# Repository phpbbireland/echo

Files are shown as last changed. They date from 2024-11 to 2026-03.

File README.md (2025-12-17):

# echo (Keyboards)
This is the final repository for all prior keyboard development code, and hardware.

Models included are: 
+ Alya: ayla80 (iso/ansi)
+ Cashel: cashel100 (ansi/iso)
+ Mioke: xpad (macro/num pad)
+ Echo: test code for RP2040 ayla80 (iso).
+ EN015_60_AKL (iso)
+ EN014 (iso) June 2025

The current STM32F411 keyboard code works for all versions, however, the RGB is not tested, to put it simply, I don't know how to implement the RGB code as including it resulted in compile errors, best use the RP2040 modulesfor now.  

Moved on to version 2.x of the Keyboard Development Modules (these have a single 34 pin 1.27mm pitch connector), otherwise they are the same...

**Latest Updates**  
I have switched to my RP2040 Development Module as everything works perfectly, no more issues with RGB...  
Going forward, I will use this for all development but may revisit my STM32F411 development board later...

**Important Notes**  
On all my Keyboad PCB's, the 34 pin connetor is mounted on component side (bottom) of PCB.  
On moules with a 34 pin connector, it is mounted on ***bottom*** of PCB, not the component side (top), see image below.  
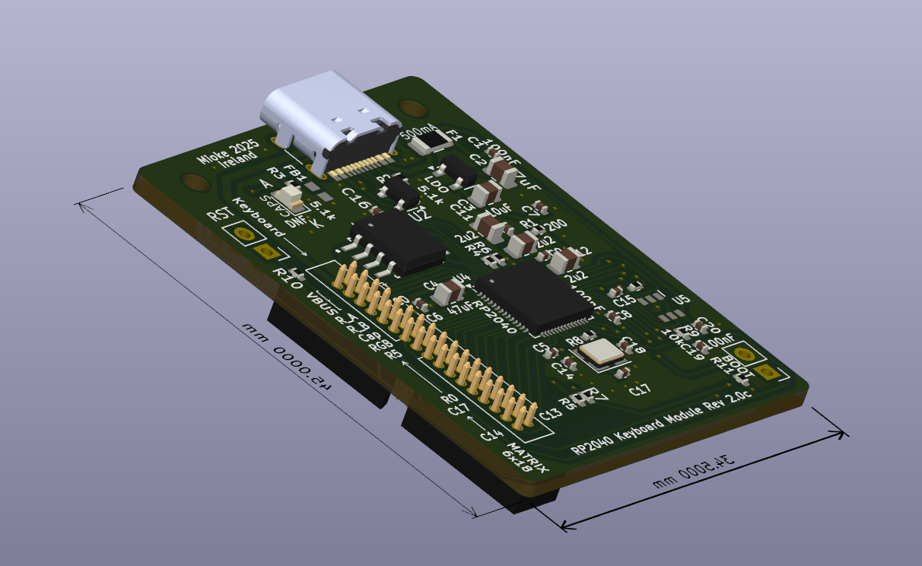
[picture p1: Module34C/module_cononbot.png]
Module


**Revision D**
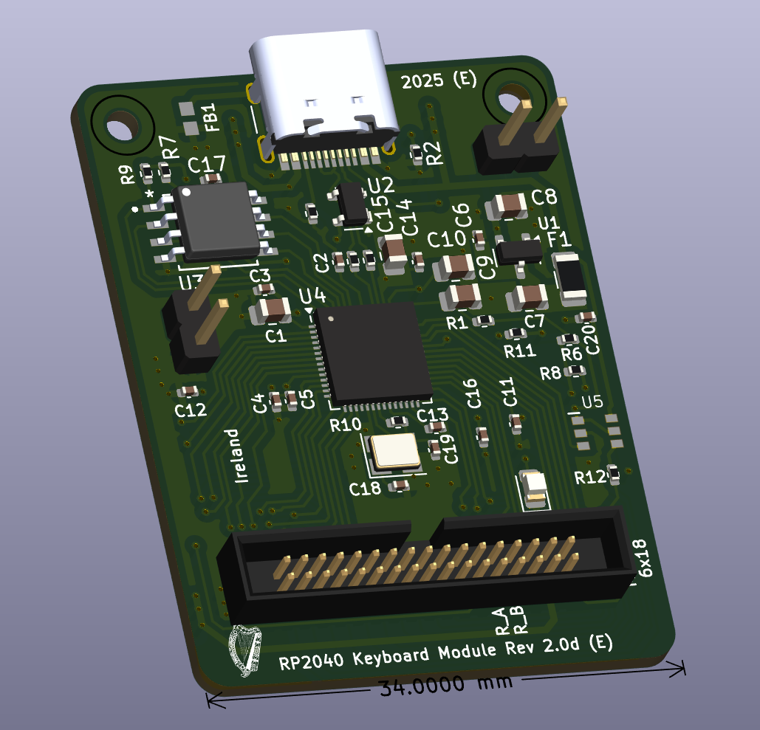
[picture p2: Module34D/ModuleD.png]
Module

*Updates:*  
+ Connector now mounted on component side...  
+ Orinitation change 90°...

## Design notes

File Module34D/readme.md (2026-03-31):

**Version D**

Micros: RP2040  
Module  

Software Supported QMK/VIA: [Link](https://github.com/phpbbireland/echo/tree/main/E014/qmk)  
Switches: MX type hot-swappable  
Keys: Up to 119 Keys (including Macro Keys) + Encoder Switch  
Rotary Encoder: Volume / RGB.  

Tested with [Basic Keyboard](https://github.com/phpbbireland/echo/tree/main/E014)

There are three Keyboard Modules (latest Rev 2D) to give away, thanks to PCBWay, if you are interested in trying out the module, contact me at my [Hackaday Link](https://hackaday.io/project/198392-keyboard-development-module-qmk-via)  

**These files may have updates, please check pin naming and orintation before prooceeding***  
I will update as time allows...

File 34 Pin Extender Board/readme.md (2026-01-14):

# Extender Board  

34 pin 1.27mm connector to 2 x 20 pin 2.54mm header adapter board.  
Kicad files included...
Gerber files update, previous has mirrored silkscreen...

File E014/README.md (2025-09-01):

# echo EN014

**Files for KiCad (ISO)**  
Final Basic Keyboard (EN014) June 18th 2025.  
Includes Plate files...  
Keyboard Layout Editer [Image, col/row numbering](https://github.com/phpbbireland/echo/blob/main/E014/images/kle_en014_keyboard_layout.png)  
Files require addition libraries: marbastlib, ScottoKeebs and library containing SK6812-E, will add soon or you can find these on github...  

**Macro Key:**  
M0 to M9 are Macro Keys, program as required...  

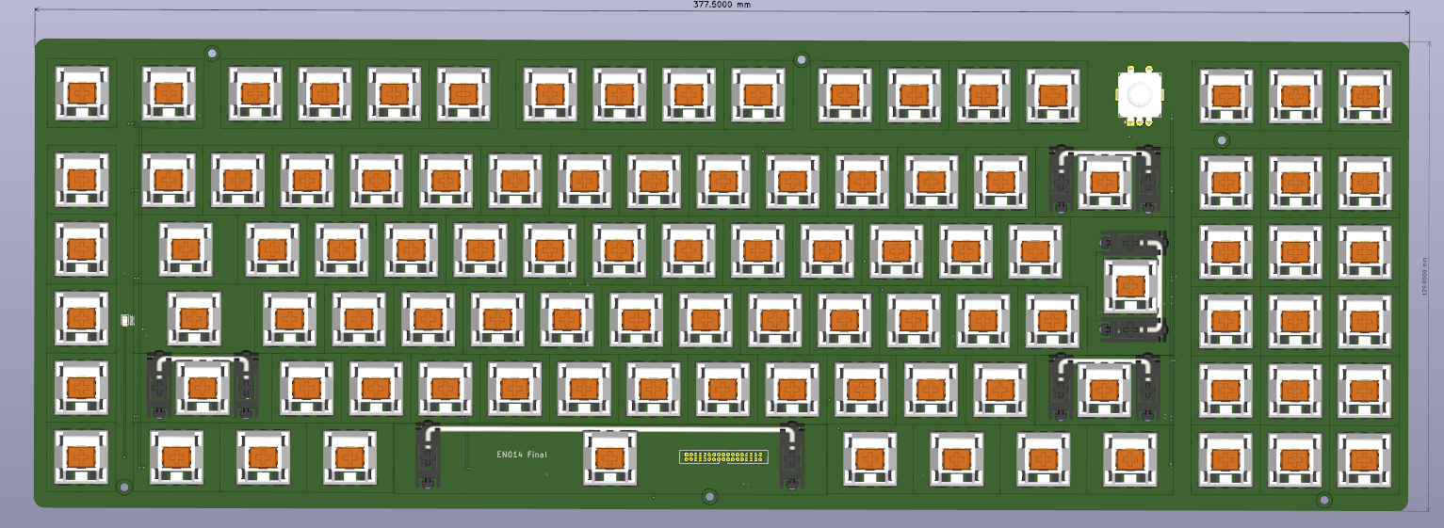
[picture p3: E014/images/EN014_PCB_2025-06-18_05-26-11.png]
PCB
The EN014 Keyboard PCB   
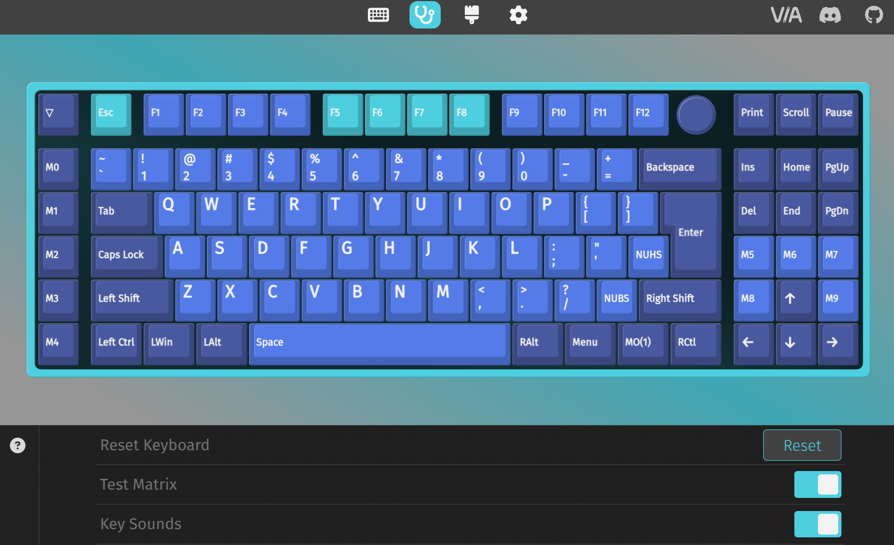
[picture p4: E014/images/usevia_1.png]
usevia
Use Via App window: 
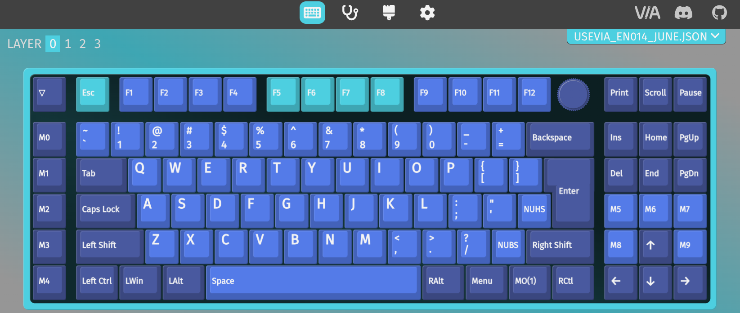
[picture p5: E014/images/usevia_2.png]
usevia

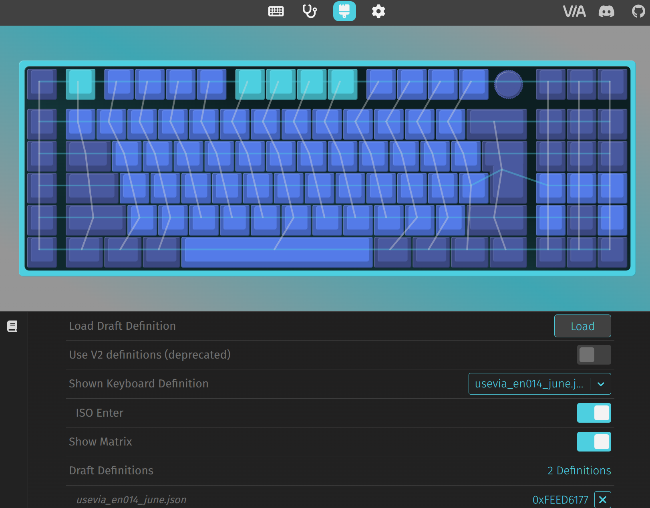
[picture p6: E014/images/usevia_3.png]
usevia
  

**Printed Case & Plate:**  
I have designed a 3D printed enclosure/case for the Keyboard, both printed in two parts with dove tail for best fit/alignment. See echo/EN14/images folder for case.png and case-top.png.
Will also included the keyboard plate print (again in two parts) as it is much cheaper than any other material and has a pleasant sound compared to other materials...

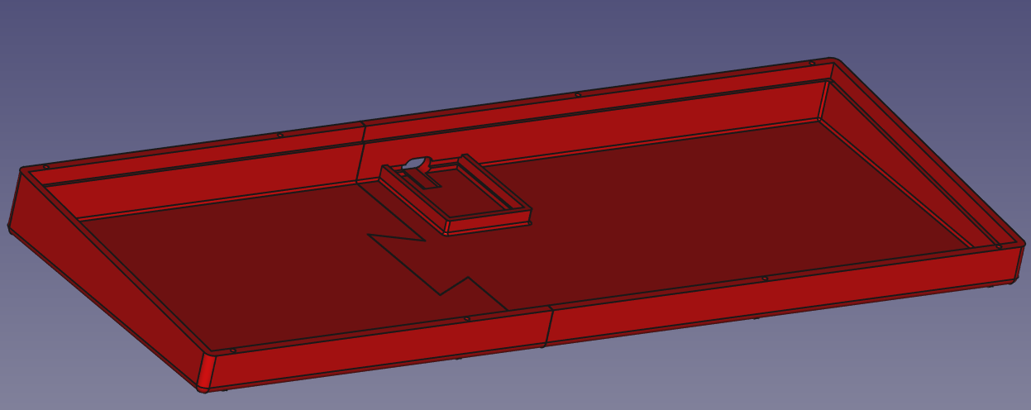
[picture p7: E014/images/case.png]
Case
  
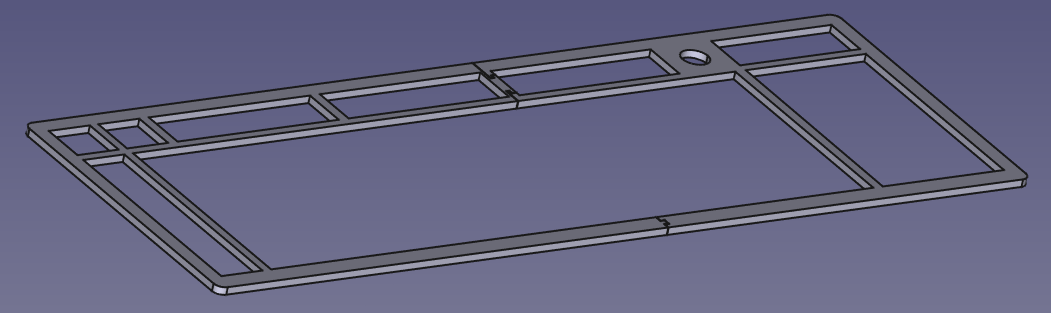
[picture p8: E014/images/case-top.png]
Case Top
  
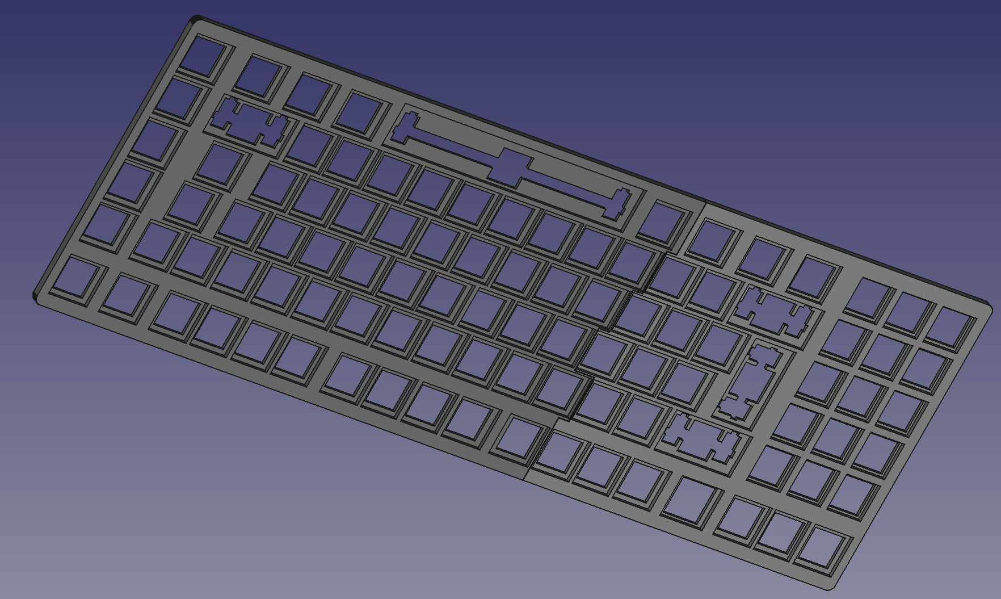
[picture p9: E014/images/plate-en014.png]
Plate
  

**Key Switches:**  
I used Holy Panda Keyboard Switch form Ali, under €20 for 110 switches (they are now my preferred switch on all my keyboards).  
For reference: Holy Panda Tactile Keyboard Switch 3 Pin 55g

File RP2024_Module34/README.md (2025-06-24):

# echo
Files to build the Basic Keyboard and RP2040 Keyboard Development Module

These have been tested with the current code and work flawlessly...
Included: 
+ RP2040_Fullsize_PCBWay_barebones... Basic Keyboard files used in all testing...
+ echo_keyboard_rp2040_module... Slightly smaller module, not produced yet...
+ echo_keyboard_rp2040_module_ori... This is the fully tested module I used in the build. [Image](https://github.com/phpbbireland/echo/blob/main/RP2024_Module34/images/RP2024_Module_Rev0.1.png)
+ iso_encoder_rp2040_en017_brd2...   The QMK and Via code for the project...

A couple of these boards are available (version 1.0, the one with the four RGB leds on it) just contact me...

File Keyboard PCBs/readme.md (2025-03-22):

# Keyboard PCB's
A repository for Keyboard PCB's Kicad Files.

**Basic Keyboard PCB**  
+ Hot-Swappable MX Connectors,
+ Diodes,
+ RBG Leds, 
+ Rotary Encoder
+ A 34 pin 1.27mm connector to connect to a development module (processor) such as my RP2040 Keyboard Development Module.

**Current Boards:**  
+ A 60% keyboard with 6 macro keys (inspired by my AKKO M1)...
+ A 80% keyboard with 12 macro keys...

**Modules:**
+ RP2040 Version 1.x (A 30 pin 1.27mm connector and a 3 pin 2.54mm connector for RGB and Power)...
+ RP2040 Version 2.x (A single 34 pin 1.27mm connector)...
+ STM32F411 Version 1.0 (A single 34 pin 1.27mm connector)...

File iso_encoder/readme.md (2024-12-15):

# echo keyboard ayla STM32F411

*This code is for the new 6x17 matrix with rotary encoder version of the board*

* Keyboard Maintainer: [Michael O'Toole](https://github.com/phpbbireland)
* Hardware Supported: *The PCBs, controllers supported*
* Hardware Availability: *Links to where you can find this hardware*
* Loads in usevia.app...
* iso and ansi...

Kicad Files: Echo_Ayla_Final

Make example for this keyboard (after setting up your build environment):

    make echo/iso_encoder:via 

Flashing example for this keyboard:

    qmk flash echo_iso_encoder_via.bin

See the [build environment setup](https://docs.qmk.fm/#/getting_started_build_tools) and the [make instructions](https://docs.qmk.fm/#/getting_started_make_guide) for more information. Brand new to QMK? Start with our [Complete Newbs Guide](https://docs.qmk.fm/#/newbs).

## Bootloader

Enter the bootloader in 3 ways:

* **Bootmagic reset**: Hold down the key at (0,0) in the matrix (usually the top left key or Escape) and plug in the keyboard
* **Physical reset button**: Briefly press the button on the back of the PCB - some may have pads you must short instead
* **Keycode in layout**: Press the key mapped to `QK_BOOT` if it is available

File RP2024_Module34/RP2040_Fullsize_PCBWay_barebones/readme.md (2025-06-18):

# echo
The kicad file to make the Basic Keyboard PCB...  
Will add kicad libraries etc later or you can find them on github, add as required...

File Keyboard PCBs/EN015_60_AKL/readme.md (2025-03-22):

# EN015_60_AKL
A 60% (89 keys including 6 macro keys) Basic Keyboard.

**Includes:**  
+ Hot-Swappable MX Connectors,
+ Diodes,
+ RBG Leds, 
+ Rotary Encoder
+ A 34 pin 1.27mm connector to connect to a development module (processor) such as my RP2040 Keyboard Development Module.

**Compatible Modules:**
+ RP2040 Version 2.x (A single 34 pin 1.27mm connector)...
+ STM32F411 Version 1.0 (A single 34 pin 1.27mm connector)...

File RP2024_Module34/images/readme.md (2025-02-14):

Connector updated to 34 pin to allow for extra current as single cable is limited to 1 Amp...

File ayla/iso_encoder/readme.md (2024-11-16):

# Echo Keyboards: Ayla (80)

*A short description of the keyboard/project*

* Keyboard Maintainer: [Michael O'Toole](https://github.com/phpbbireland)
* Hardware Supported: *The PCBs, controllers supported*
* Hardware Availability: *Links to where you can find this hardware*

Make example for this keyboard (after setting up your build environment):

    make ayla/iso_encoder:via

Flashing example for this keyboard:

    qmk flash ayla_iso_encoder_via.bin

See the [build environment setup](https://docs.qmk.fm/#/getting_started_build_tools) and the [make instructions](https://docs.qmk.fm/#/getting_started_make_guide) for more information. Brand new to QMK? Start with our [Complete Newbs Guide](https://docs.qmk.fm/#/newbs).

## Bootloader

Current:
* **Blackpill Module** Hold down BOOT button (on Blackpill module),then press and release NRST, release BOOT...

Not implemented yet...

* **Bootmagic reset**: Hold down the key at (0,0) in the matrix (usually the top left key or Escape) and plug in the keyboard
* **Physical reset button**: Briefly press the button on the back of the PCB - some may have pads you must short instead
* **Keycode in layout**: Press the key mapped to `QK_BOOT` if it is available

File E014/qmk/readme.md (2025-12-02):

# Echo EN014 Keyboard Code (June 24th)

+ Create an **echo/en014_june** directory inside: qmk_firmware/keyboards/  
+ Copy all files to qmk_firmware/keyboards/echo/en014_june
+ Change back to the qmk_firmware directory
+ Compile with: make echo/en014_june:via    
+ Copy resulting file (echo_en014_june_via.uf2) to the Module Board (Version 2.x)  

**Note:**
echo.c and echo.h are not required, will remove them (appears to be old method), all RGB matrix data now in keyboard.json.  

**Testing the Module:**  
1 In **Chrome** browser, browse to: https://usevia.app/  
2 Authorize the Keyboard, select: *Michael O'Toole Echo*  
3 Click on the *Design Icon* and browse to the **usevia_en014_june.json** file, select it.  
4 You may need to go back to step 2 and select keyboard again (I do), then test away...  

**More Notes:**  
Tested keyboard operation and RGB, with *Keyboard Development Module* version 2.0, module and code work perfectly.  
EN014 keyboard was designed to work with Module 2.x (the version with the 34 pin connector)...  

Contains electronic files for en014 june 24th

**File to load with usevia.app**  
usevia_en014_june.json

**Compile command for QMK**  
make echo/en014_june:via

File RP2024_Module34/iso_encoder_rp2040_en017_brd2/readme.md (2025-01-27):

# Echo Keyboard with PR2040

Repository for RP2040 keyboard development code, and hardware.  

*Models included are:*
+ Small Development Module/Board for Software Development [link to board](https://hackaday.io/project/198392/log/237192-rp2040-version).
+ Full Keyboard (98 keys/RGB leds, hot-swappable connectors etc.) [link to board](https://hackaday.io/project/202280-basic-hot-swappable-keyboard-with-rgb)
  
Awaiting Development Module (Dec/Jan)...

```
                 ┌─────────┬─────────┬─────────┬─────────┬─────────┬─────────┬─────────┬─────────┬─────────┬─────────┬─────────┬─────────┬─────────┬─────────┬─────────┬─────────┬─────────┬─────────┐
  ┌────────RP2040│  GP0    │   GP1   │   GP2   │   GP3   │   GP4   │   GP5   │   GP6   │   GP7   │   GP8   │   GP9   │  GP10   │  GP11   │  GP12   │   GP13  │  GP14   │  GP16   │  GP17   │  GP18   │
  │              └─────────┴─────────┴─────────┴─────────┴─────────┴─────────┴─────────┴─────────┴─────────┴─────────┴─────────┴─────────┴─────────┴─────────┴─────────┴─────────┴─────────┴─────────┘
  │              ┌─────────┬─────────┬─────────┬─────────┬─────────┬─────────┬─────────┬─────────┬─────────┬─────────┬─────────┬─────────┬─────────┬─────────┬─────────┬─────────┬─────────┬─────────┐
  │     ┌─STMF411│   C13   │   C14   │   C15   │   C0    │   C1    │   C2    │   C3    │   A1    │   A2    │   A4    │   A5    │   A6    │   A7    │   C4    │   C5    │   B0    │   B1    │   B2    │
  │     │        └─────────┴─────────┴─────────┴─────────┴─────────┴─────────┴─────────┴─────────┴─────────┴─────────┴─────────┴─────────┴─────────┴─────────┴─────────┴─────────┴─────────┴─────────┘
  │     │   ┌────┬─────────┬─────────┬─────────┬─────────┬─────────┬─────────┬─────────┬─────────┬─────────┬─────────┬─────────┬─────────┬─────────┬─────────┬─────────┬─────────┬─────────┬─────────┐
  │     │   │    │  COL0   │  COL1   │  COL2   │  COL3   │  COL4   │  COL5   │  COL6   │  COL7   │  COL8   │  COL9   │  COL10  │  COL11  │  COL12  │  COL13  │  COL14  │  COL15  │  COL16  │  COL17  │
┌────┐┌───┐ ├────┼─────────┼─────────┼─────────┼─────────┼─────────┼─────────┼─────────┼─────────┼─────────┼─────────┼─────────┼─────────┼─────────┼─────────┼─────────┼─────────┼─────────┼─────────┤
│GP19││C8 │ │ROW0│ RESET   │ KC_ESC  │ KC_TRNS │ KC_F1   │ KC_F2   │ KC_F3   │ KC_F4   │ KC_F5   │ KC_F6   │ KC_F7   │ KC_F8   │ KC_F9   │ KC_F10  │ KC_F11  │ KC_F12  │ KC_PSCR │ KC_SCRL │ KC_PAUSE│
├────┤├───┤ ├────┼─────────┼─────────┼─────────┼─────────┼─────────┼─────────┼─────────┼─────────┼─────────┼─────────┼─────────┼─────────┼─────────┼─────────┼─────────┼─────────┼─────────┼─────────┤
│GP20││C7 │ │ROW1│ KC_TRNS │ KC_GRV  │ KC_1    │ KC_2    │ KC_3    │ KC_4    │ KC_5    │ KC_6    │ KC_7    │ KC_8    │ KC_9    │ KC_0    │ KC_MINS │ KC_EQL  │ KC_BSPC │ KC_INS  │ KC_HOME │ KC_PGUP │
├────┤├───┤ ├────┼─────────┼─────────┼─────────┼─────────┼─────────┼─────────┼─────────┼─────────┼─────────┼─────────┼─────────┼─────────┼─────────┼─────────┼─────────┼─────────┼─────────┼─────────┤
│GP21││C6 │ │ROW2│ KC_TRNS │ KC_TAB  │ KC_Q    │ KC_W    │ KC_E    │ KC_R    │ KC_T    │ KC_Y    │ KC_U    │ KC_I    │ KC_O    │ KC_P    │ KC_LBRC │ KC_RBRC │         │ KC_DEL  │ KC_END  │ KC_PGDN │
├────┤├───┤ ├────┼─────────┼─────────┼─────────┼─────────┼─────────┼─────────┼─────────┼─────────┼─────────┼─────────┼─────────┼─────────┼─────────┼─────────┼─────────┼─────────┼─────────┼─────────┤
│GP22││B15│ │ROW3│ KC_TRNS │ KC_CAPS │ KC_A    │ KC_S    │ KC_D    │ KC_F    │ KC_G    │ KC_H    │ KC_J    │ KC_K    │ KC_L    │ KC_SCLN │ KC_QUOT │ KC_NUHS │ KC_ENTR │ KC_TRNS │ KC_TRNS │ KC_TRNS │
├────┤├───┤ ├────┼─────────┼─────────┼─────────┼─────────┼─────────┼─────────┼─────────┼─────────┼─────────┼─────────┼─────────┼─────────┼─────────┼─────────┼─────────┼─────────┼─────────┼─────────┤
│GP23││B14│ │ROW4│ KC_TRNS │ KC_LSFT │ KC_Z    │ KC_X    │ KC_C    │ KC_V    │ KC_B    │ KC_N    │ KC_M    │ KC_COMM │ KC_DOT  │ KC_SLSH │ KC_NUBS │ KC_RSFT │         │ KC_TRNS │ KC_UP   │ KC_TRNS │
├────┤├───┤ ├────┼─────────┼─────────┼─────────┼─────────┼─────────┼─────────┼─────────┼─────────┼─────────┼─────────┼─────────┼─────────┼─────────┼─────────┼─────────┼─────────┼─────────┼─────────┤
│GP24││B13│ │ROW5│ KC_TRNS │ KC_LCTL │ KC_LGUI │ KC_LALT │         │         │         │ KC_SPC  │         │         │         │ KC_RALT │ KC_MENU │ M0(FN)  │ KC_RCTL │ KC_LEFT │ KC_DOWN │ KC_RIGHT│
└────┘└───┘ └────┴─────────┴─────────┴─────────┴─────────┴─────────┴─────────┴─────────┴─────────┴─────────┴─────────┴─────────┴─────────┴─────────┴─────────┴─────────┴─────────┴─────────┴─────────┘
```

Matrix Col/Row to GPIO's : RP2040 and STM32F411

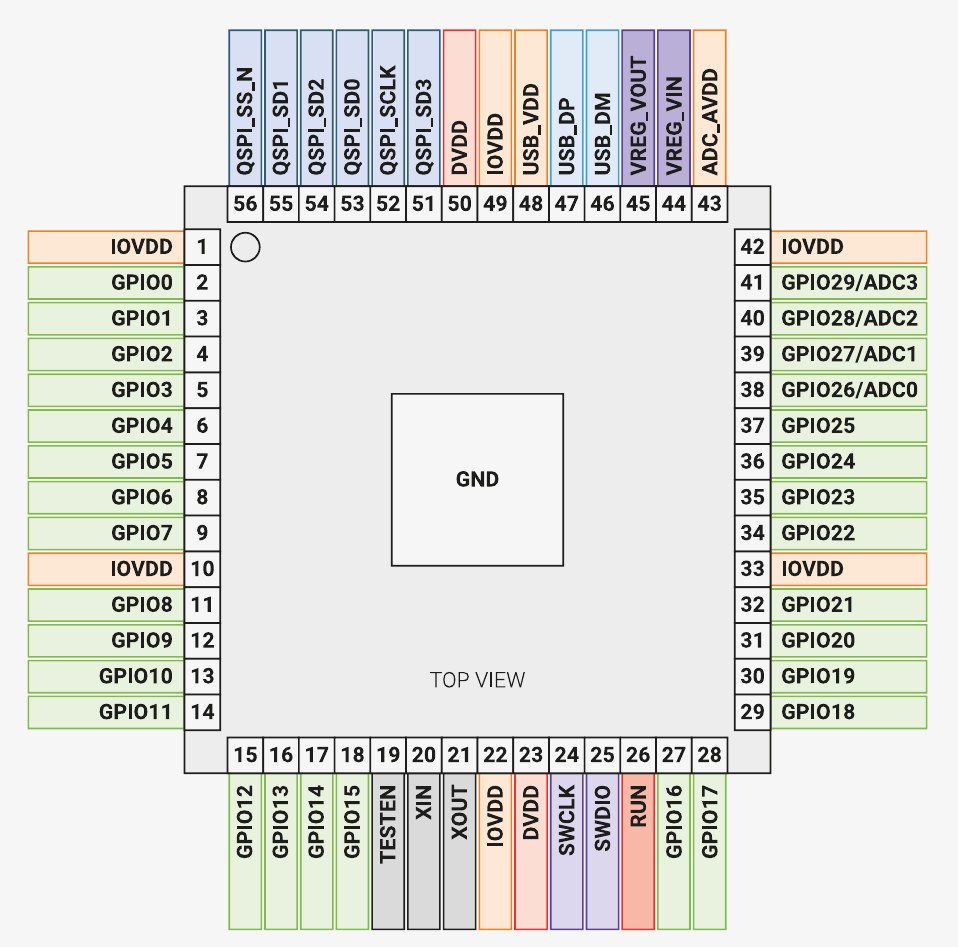
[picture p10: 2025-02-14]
RP2024_Module34/echo_keyboard_rp2040_module_ori/RP2040 Pinout.png

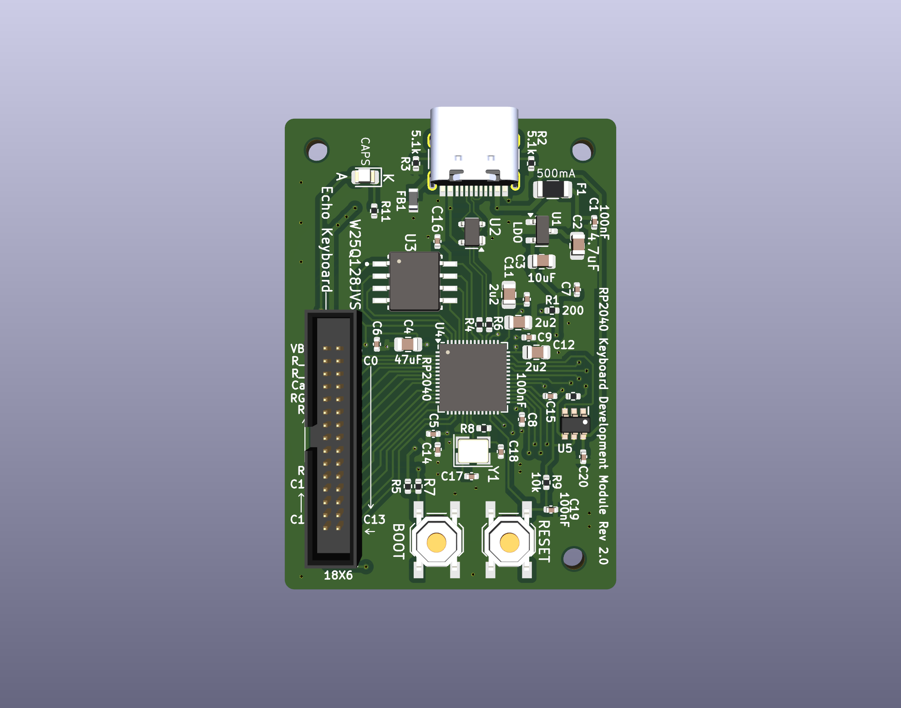
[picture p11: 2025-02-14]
RP2024_Module34/images/RP2024_Module_Rev2.0.png

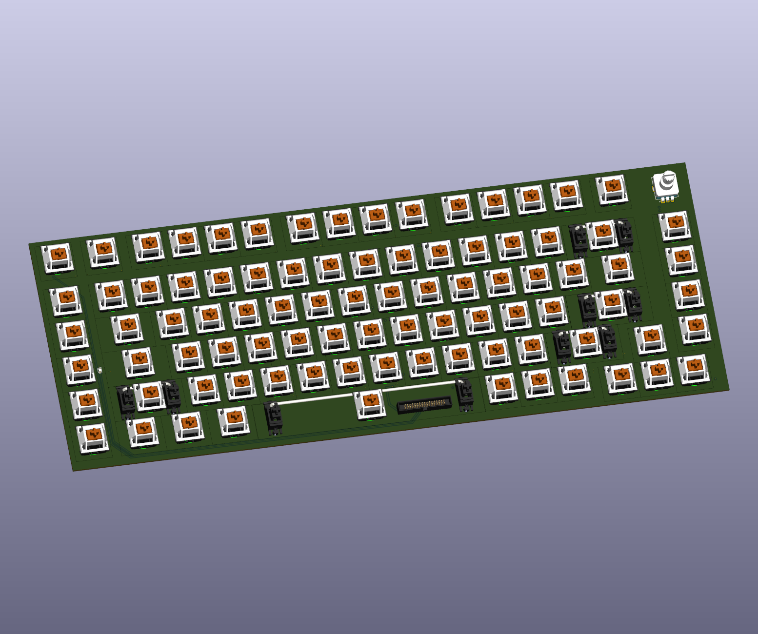
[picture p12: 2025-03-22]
Keyboard PCBs/EN015_60_AKL/images/RP2040_Akko_M1_Like2.png

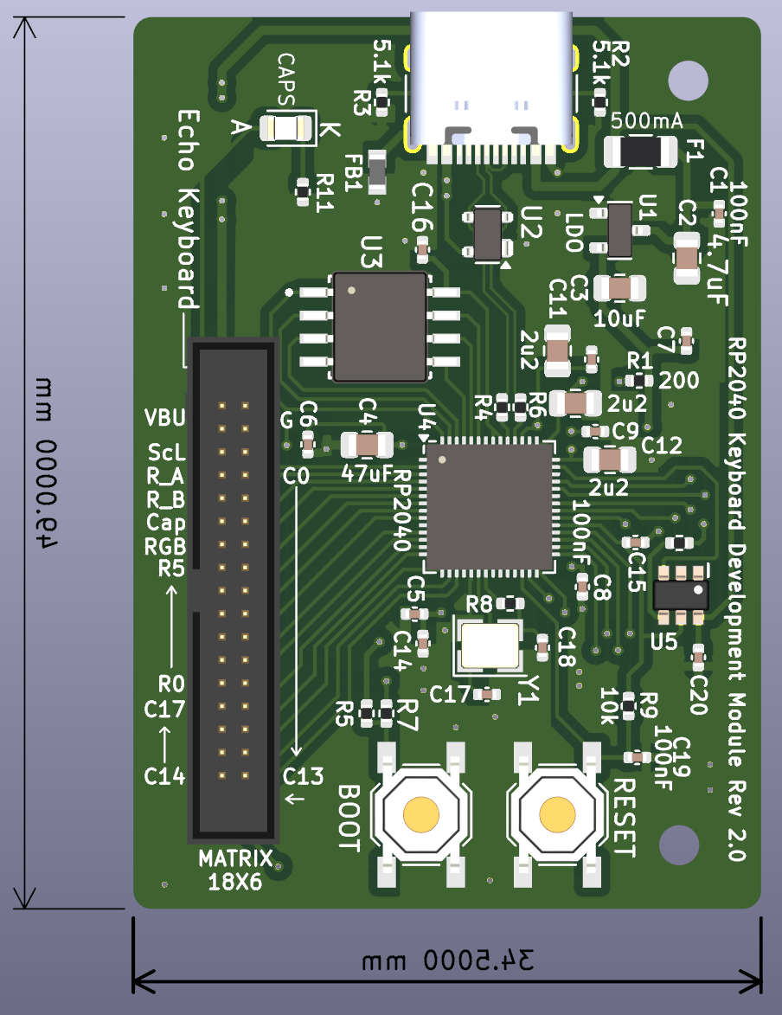
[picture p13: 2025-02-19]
RP2024_Module34/images/RP2024_Module_Rev1.0.png

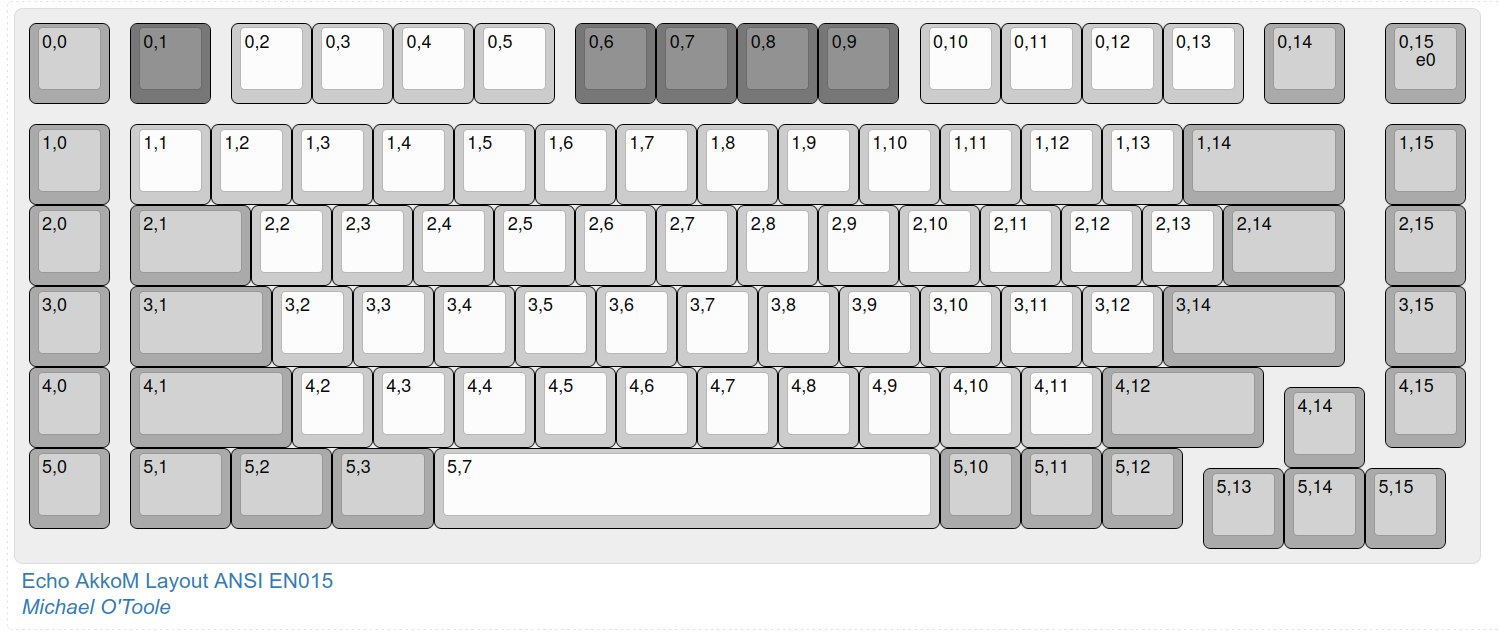
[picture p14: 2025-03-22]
Keyboard PCBs/EN015_60_AKL/images/KLE_Image.png

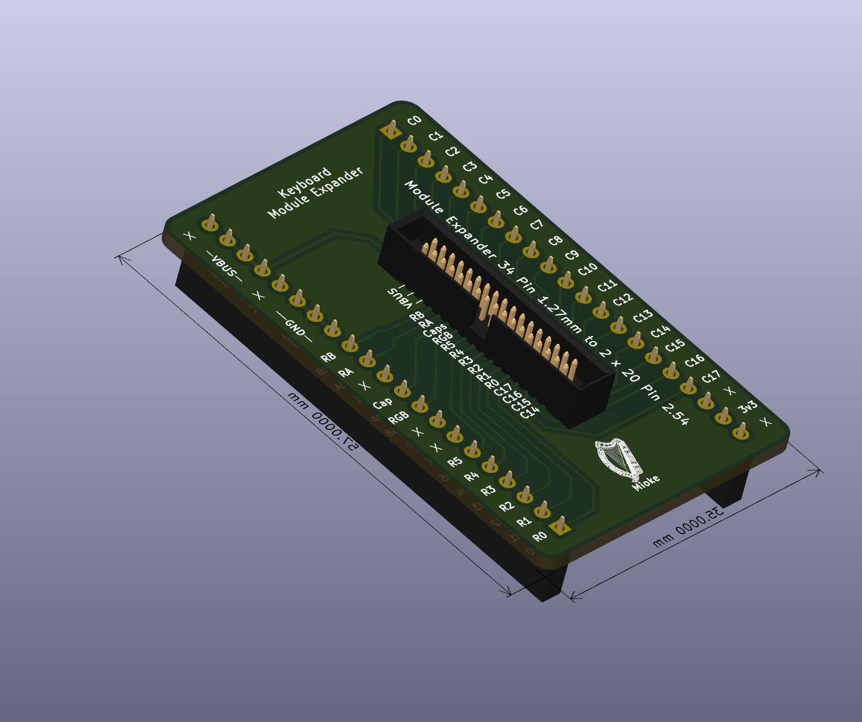
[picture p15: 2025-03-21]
RP2024_Module34/images/adapter34.png

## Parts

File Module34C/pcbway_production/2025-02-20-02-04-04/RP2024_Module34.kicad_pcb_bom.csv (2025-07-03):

Designator | Quantity | Value | Footprint | Package | MPN | DNP | Mount_Type | LCSC | Description | JlcRotOffset | JlcPosOffset | MFP# | MP# | Mfr. Part # | MPN | JLCPCB_CORRECTION
C1, C10, C14, C15, C16, C19, C20, C5, C6, C7, C8, C9 | 12 | 100nF | C_0402_1005Metric | 0402 | CL05B104KB54PNC |  | smt | C307331 | Multilayer Ceramic Capacitors
C11, C12, C13 | 3 | 2u2 | C_0805_2012Metric | 0805 | CL21B225KAFNNNE |  | smt | C19110 | Multilayer Ceramic Capacitors
C17, C18 | 2 | 15p | C_0402_1005Metric | 0402 | CL05C150JB5NNNC |  | smt | C86285 | Multilayer Ceramic Capacitors
C2 | 1 | 4.7uF | C_0805_2012Metric | 0805 | CL21A475KAQNNNE |  | smt | C1779 | Multilayer Ceramic Capacitors
C3 | 1 | 10uF | C_0805_2012Metric | 0805 | CL21A106KOQNNNE |  | smt | C1713 | Multilayer Ceramic Capacitors
C4 | 1 | 47uF | C_0805_2012Metric | 0805 | CL21A476MQYNNNE |  | smt | C16780 | Multilayer Ceramic Capacitors
F1 | 1 | 500mA | Fuse_1206_3216Metric | 1206 | ASMD1206-150 |  | smt | C135341 | Multilayer Ceramic Capacitors
FB1 | 1 | 600R | BEADC1608X95N | 0603 | BLM18AG601SN1D |  | smt | C19330 | Ferrite bead, small symbol
J1 | 1 | USB_C_Receptacle_USB2.0 | USB_C_31-M-12 | SMD | TYPE-C-31-M-12A |  | smt | C5337088 | USB 2.0-only 16P Type-C Receptacle connector | 180 | 0,1.5 | TYPE-C-31-M-12A
J3 | 1 | Conn_02x17_Odd_Even | IDC_2X17_1.27MM | IDC Connectors | X1270WV-2x17B-6TV01 |  | tht | C5147222 | Generic connector, double row, 02x17, odd/even pin numbering
LED1 | 1 | Led | LED_0805_2012Metric | 0805 | D-B080508B1-KS2 |  | smt | C108412 | Light emitting diode, small symbol, filled shape
R1 | 1 | 200 | R_0402_1005Metric | 0402 | 0402WGJ0512TCE |  | smt | C25941 | Resistor, small symbol
R10, R12, R4, R6 | 4 | 27 | R_0402_1005Metric | 0402 | 0402WGF270JTCE |  | smt | C25100 | Resistor, small symbol |  |  |  | 0402WGF270JTCE
R11 | 1 | 1K | R_0402_1005Metric | 0402 | 0402WGF1001TCE |  | smt | C11702 | Resistor, small symbol
R2, R3 | 2 | 5.1k | R_0402_1005Metric | 0402 | 0402WGF5101TCE |  | smt | C25905 | Resistor
R5, R9 | 2 | 10k | R_0402_1005Metric | 0402 | 0402WGF1002TCE |  | smt | C25744 | Resistor
R7, R8 | 2 | 1k | R_0402_1005Metric | 0402 | 0402WGF1001TCE |  | smt | C11702 | Resistor, small symbol
U1 | 1 | XC6206PxxxMR-Regulator_Linear | SOT-23 | SOT-23-3L | XC6206P332MR-G |  | smt | C5446 | 200mA Fixed 3.3V SOT-23-3L Voltage Regulators – Linear
U2 | 1 | PRTR5V0U2X | SOT-143 | SOT-143-4 | PRTR5V0U2X |  | smt | C2827688 | 6A 100W 15V 6.5V Unidirectional 5V SOT-143-4 ESD and Surge Protection | 90 |  | PRTR5V0U2X
U3 | 1 | W25Q128JVS | SOIC_128JVSIQ_WIN | SOIC-8-208mil | W25Q128JVSIQ |  | smt | C97521 | 128Mb Serial Flash Memory, Standard/Dual/Quad SPI, SOIC-8 |  |  |  |  | W25Q128JVSIQ
U4 | 1 | RP2040 | QFN-56-1EP_7x7mm_P0.4mm_EP3.2x3.2mm | LQFN-56(7x7) | RP2040 |  | smt | C2040 | A microcontroller by Raspberry Pi |  |  | RP2040
U5 | 1 | 74LVC1T45 | SOT-26 | SOT-26 | 74LVC1T45W6-7 |  | smt | C168856 | 1.65V~5.5V 1 1 1.65V~5.5V SOT-26 Translators, Level Shifters ROHS |  |  |  |  |  | 74LVC1T45W6-7 | 0; 0; 270
Y1 | 1 | 12Mhz | Crystal_SMD_3225-4Pin_3.2x2.5mm | SMD3225-4P | ABM8-272-T3 |  | smt | C20625731 | Four pin crystal, GND on pins 2 and 4, small symbol |  |  | ABM8-272-T3

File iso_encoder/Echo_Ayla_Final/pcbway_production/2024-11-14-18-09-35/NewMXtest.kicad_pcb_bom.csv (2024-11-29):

Designator | Quantity | Value | Footprint | Package | MPN | DNP | Mount_Type | LCSC | Description | Sim.Device | Sim.Pins | JlcRotOffset | JlcPosOffset | MF | Description_1 | Price | SnapEDA_Link | MP | Check_prices
BOOT1, RST1 | 2 | SW_SPST | SW_SPST_TL3342 | SMD | TL3342F450QG |  | smt | C2886897 | Switch
C1 | 1 | 47uF | C_0805_2012Metric | 0805 | CL21A476MQYNNNE |  | smt | C16780 | Capacitor
C10, C11 | 2 | 12p | C_0402_1005Metric | 0402 | CL05C120JB5NNNC |  | smt | C26406 | Capacitor
C12 | 1 | 2u2 | C_0805_2012Metric | 0805 | CL21B225KAFNNNE |  | smt | C19110 | Capacitor
C13, C2, C3, C4, C5, C6, C7, C8, C9 | 9 | 100nF | C_0402_1005Metric | 0402 | 0402F104M500NT |  | smt | C1581 | Capacitor
C14 | 1 | 1uF | C_0805_2012Metric | 0805 | CL21B105KAFNFNE |  | smt | C1712 | Capacitor
C15 | 1 | 10uF | C_0805_2012Metric | 0805 | CL21A106KOQNNNE |  | smt | C1713 | Capacitor
C16, C17 | 2 | 10n | C_0805_2012Metric | 0805 | ECHU1C103JX5 |  | smt | C178414 | Unpolarized capacitor, small symbol
D1, D10, D100, D11, D12, D13, D14, D15, D16, D17, D18, D19, D2, D20, D21, D22, D23, D24, D25, D26, D27, D28, D29, D3, D30, D31, D32, D33, D34, D35, D36, D37, D38, D39, D4, D40, D41, D42, D43, D44, D45, D46, D47, D48, D49, D5, D50, D51, D52, D53, D54, D55, D56, D57, D58, D59, D6, D60, D61, D62, D63, D64, D65, D66, D67, D68, D69, D7, D70, D71, D72, D73, D74, D75, D76, D77, D78, D79, D8, D80, D81, D82, D83, D84, D85, D86, D87, D88, D89, D9, D90, D91, D92, D93, D94, D95, D96, D97, D98, D99 | 100 | 4148 | Diode_SOD-123 | SOD-123 | 1N4148W |  | smt | C84367 | Diode, small symbol | D | 1=K 2=A
F1 | 1 | 500mA | Fuse_1206_3216Metric | 1206 | ASMD1206-150 |  | smt | C135341 | Fuse
FB1 | 1 | 600R | BEADC1608X95N | 0603 | BLM18AG601SN1D |  | tht | C19330 | Ferrite bead, small symbol
J1 | 1 | USB_C_Receptacle_USB2.0 | USB_C_Receptacle_HRO_TYPE-C-31-M-12 | SMD | TYPE-C-31-M-12A |  | smt | C5337088 | USB Connector |  |  | 180 | 0,1.5
R1 | 1 | 22 | R_0402_1005Metric | 0402 | 0402WGJ0220TCE |  | smt | C25152 | Resistor
R2 | 1 | 220 | R_0402_1005Metric | 0402 | 0402WGJ0221TCE |  | smt | C25151 | Resistor
R3, R4, R5, R6 | 4 | 5.1k | R_0402_1005Metric | 0402 | 0402WGJ0512TCE |  | smt | C25941 | Resistor
RGB1, RGB10, RGB11, RGB12, RGB13, RGB14, RGB15, RGB16, RGB17, RGB18, RGB19, RGB2, RGB20, RGB21, RGB22, RGB23, RGB24, RGB25, RGB26, RGB27, RGB28, RGB29, RGB3, RGB30, RGB31, RGB32, RGB33, RGB34, RGB35, RGB36, RGB37, RGB38, RGB39, RGB4, RGB40, RGB41, RGB42, RGB43, RGB44, RGB45, RGB46, RGB47, RGB48, RGB49, RGB5, RGB50, RGB51, RGB52, RGB53, RGB54, RGB55, RGB56, RGB57, RGB58, RGB59, RGB6, RGB60, RGB61, RGB62, RGB63, RGB64, RGB65, RGB66, RGB67, RGB68, RGB69, RGB7, RGB70, RGB71, RGB72, RGB73, RGB74, RGB75, RGB76, RGB77, RGB78, RGB79, RGB8, RGB80, RGB81, RGB82, RGB83, RGB84, RGB85, RGB86, RGB87, RGB88, RGB89, RGB9, RGB90, RGB91, RGB92, RGB93, RGB94, RGB95, RGB96, RGB97, RGB98, RGB99 | 99 | SK6812-E | SK6812-E | SMD | SK6812MINI-E |  | smt | C5149201 | [RGB1-RGB99] RGB LED with integrated controllerBackMount;
U1 | 1 | 74LVC1T45 | SOT-563 | SOT-563 | 74LVC1T45Z6-7 |  | smt | C441819 | 1.65V~5.5V 1 1 1.65V~5.5V SOT-563 Translators, Level Shifters ROHS
U2 | 1 | STM32F411RETx | LQFP-64_10x10mm_P0.5mm | LQFP-64(10x10) | STM32F411RET6 |  | smt | C94355 | STMicroelectronics Arm Cortex-M4 MCU, 512KB flash, 128KB RAM, 100 MHz, 1.7-3.6V, 50 GPIO, LQFP64
U3 | 1 | XC6206PxxxMR-Regulator_Linear | SOT-23 | SOT-23-3L | XC6206P332MR-G |  | smt | C5446 | 200mA Fixed 3.3V Positive electrode 6V SOT-23-3L Voltage Regulators
U4 | 1 | PRTR5V0U2X | SOT-143 | SOT-143-4 | PRTR5V0U2X |  | smt | C2827688 | ESD protection diode |  |  | 90
Y1 | 1 | 16Mhz | Crystal_SMD_3225-4Pin_3.2x2.5mm | SMD3225-4P | X322516MOB4SI |  | smt | C12668 | 16MHz Surface Mount Crystal 12pF ±10ppm ±20ppm SMD3225-4P Crystals ROHS

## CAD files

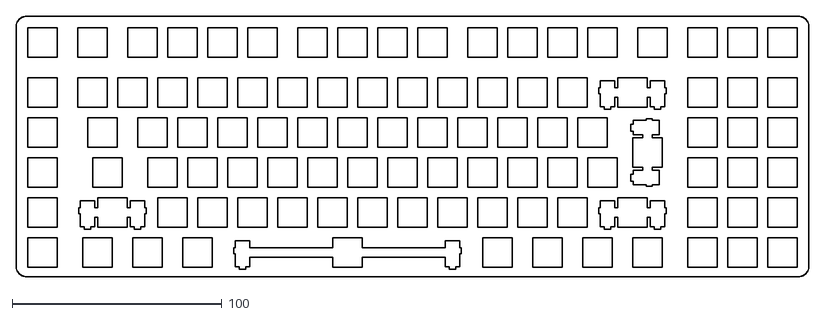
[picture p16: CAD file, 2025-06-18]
E014/5mm3b_switch.dxf
377.5 x 124.1

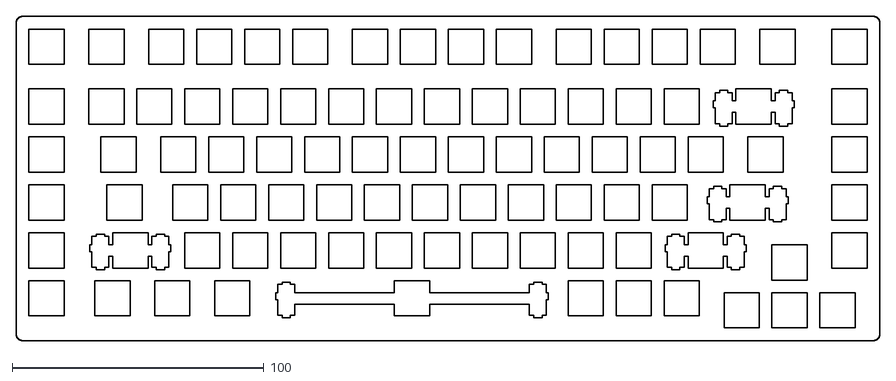
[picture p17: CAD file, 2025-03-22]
Keyboard PCBs/EN015_60_AKL/Plate/2.5sqr.dxf
343.1 x 128.8

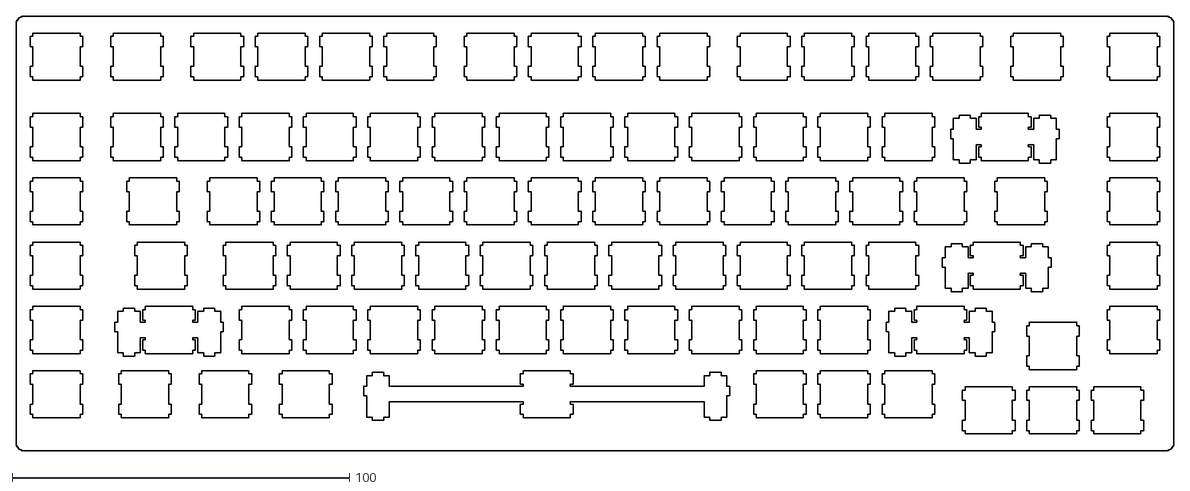
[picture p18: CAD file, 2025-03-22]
Keyboard PCBs/EN015_60_AKL/Plate/2.5.dxf
343.1 x 128.8

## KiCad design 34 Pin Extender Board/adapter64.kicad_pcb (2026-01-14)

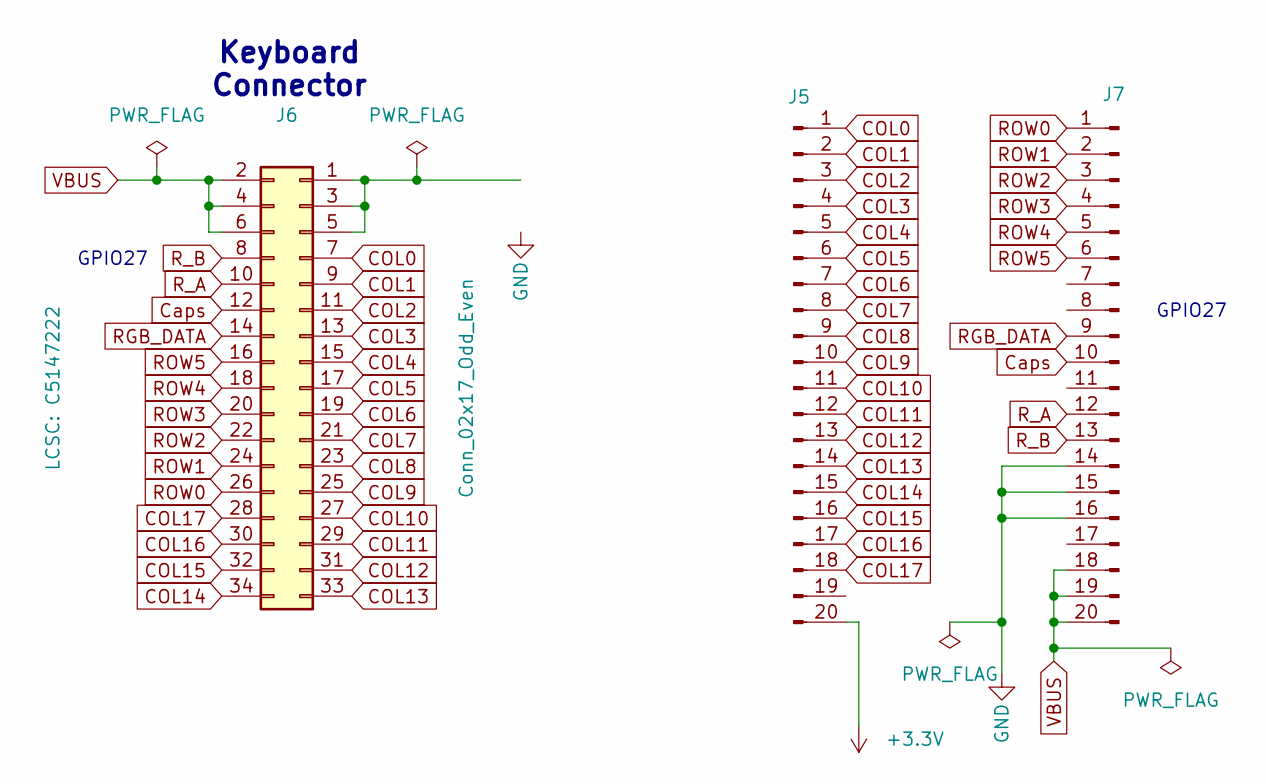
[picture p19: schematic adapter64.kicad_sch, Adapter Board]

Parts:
J5, J7: Conn_01x21_Pin; PinSocket_1x21_P2.54mm_Vertical
J6: Conn_02x17_Odd_Even; IDC_2X17_1.27MM; LCSC C5147222

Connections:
+3.3V: J5.20
COL0: J5.1, J6.7
COL1: J5.2, J6.9
COL2: J5.3, J6.11
COL3: J5.4, J6.13
COL4: J5.5, J6.15
COL5: J5.6, J6.17
COL6: J5.7, J6.19
COL7: J5.8, J6.21
COL8: J5.9, J6.23
COL9: J5.10, J6.25
COL10: J5.11, J6.27
COL11: J5.12, J6.29
COL12: J5.13, J6.31
COL13: J5.14, J6.33
COL14: J5.15, J6.34
COL15: J5.16, J6.32
COL16: J5.17, J6.30
COL17: J5.18, J6.28
Caps: J6.12, J7.10
GND: J7.14, J7.15, J7.16
unnamed: J6.1, J6.3, J6.5
RGB_DATA: J6.14, J7.9
ROW0: J6.26, J7.1
ROW1: J6.24, J7.2
ROW2: J6.22, J7.3
ROW3: J6.20, J7.4
ROW4: J6.18, J7.5
ROW5: J6.16, J7.6
R_A: J6.10, J7.12
R_B: J6.8, J7.13
VBUS: J6.2, J6.4, J6.6, J7.18, J7.19, J7.20

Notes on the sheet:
Keyboard Connector
GPIO27

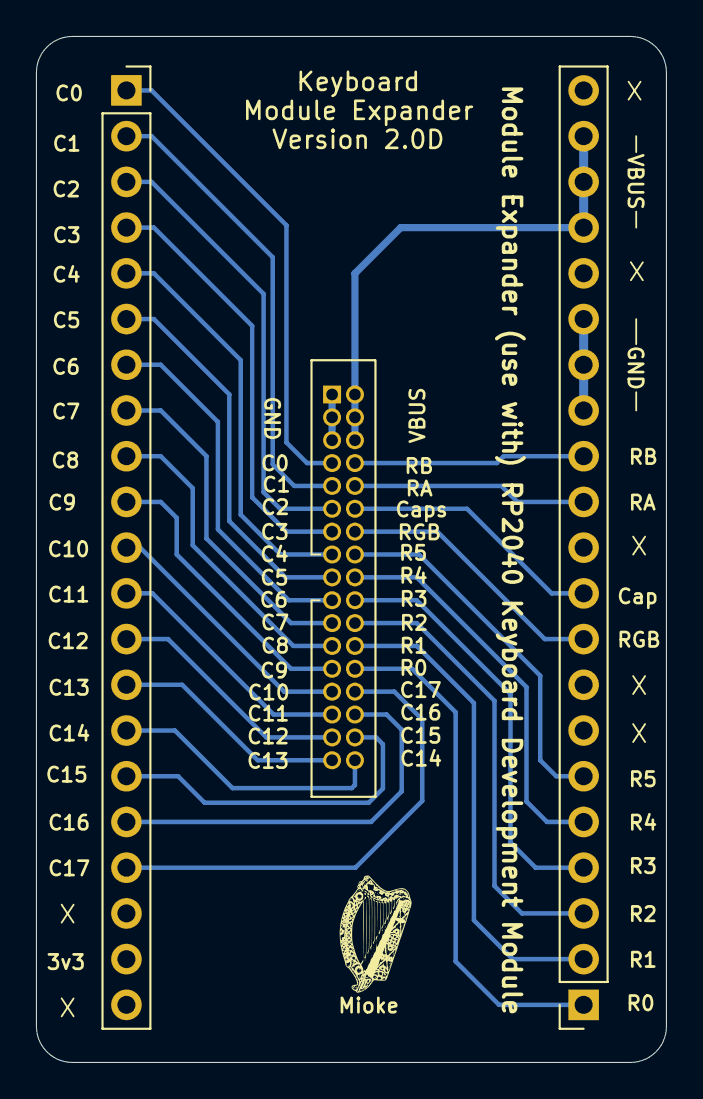
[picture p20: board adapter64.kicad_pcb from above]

Board: 2 copper layers, 35.0 x 57.0 mm, 3 parts (0 on the bottom side), 31 nets.

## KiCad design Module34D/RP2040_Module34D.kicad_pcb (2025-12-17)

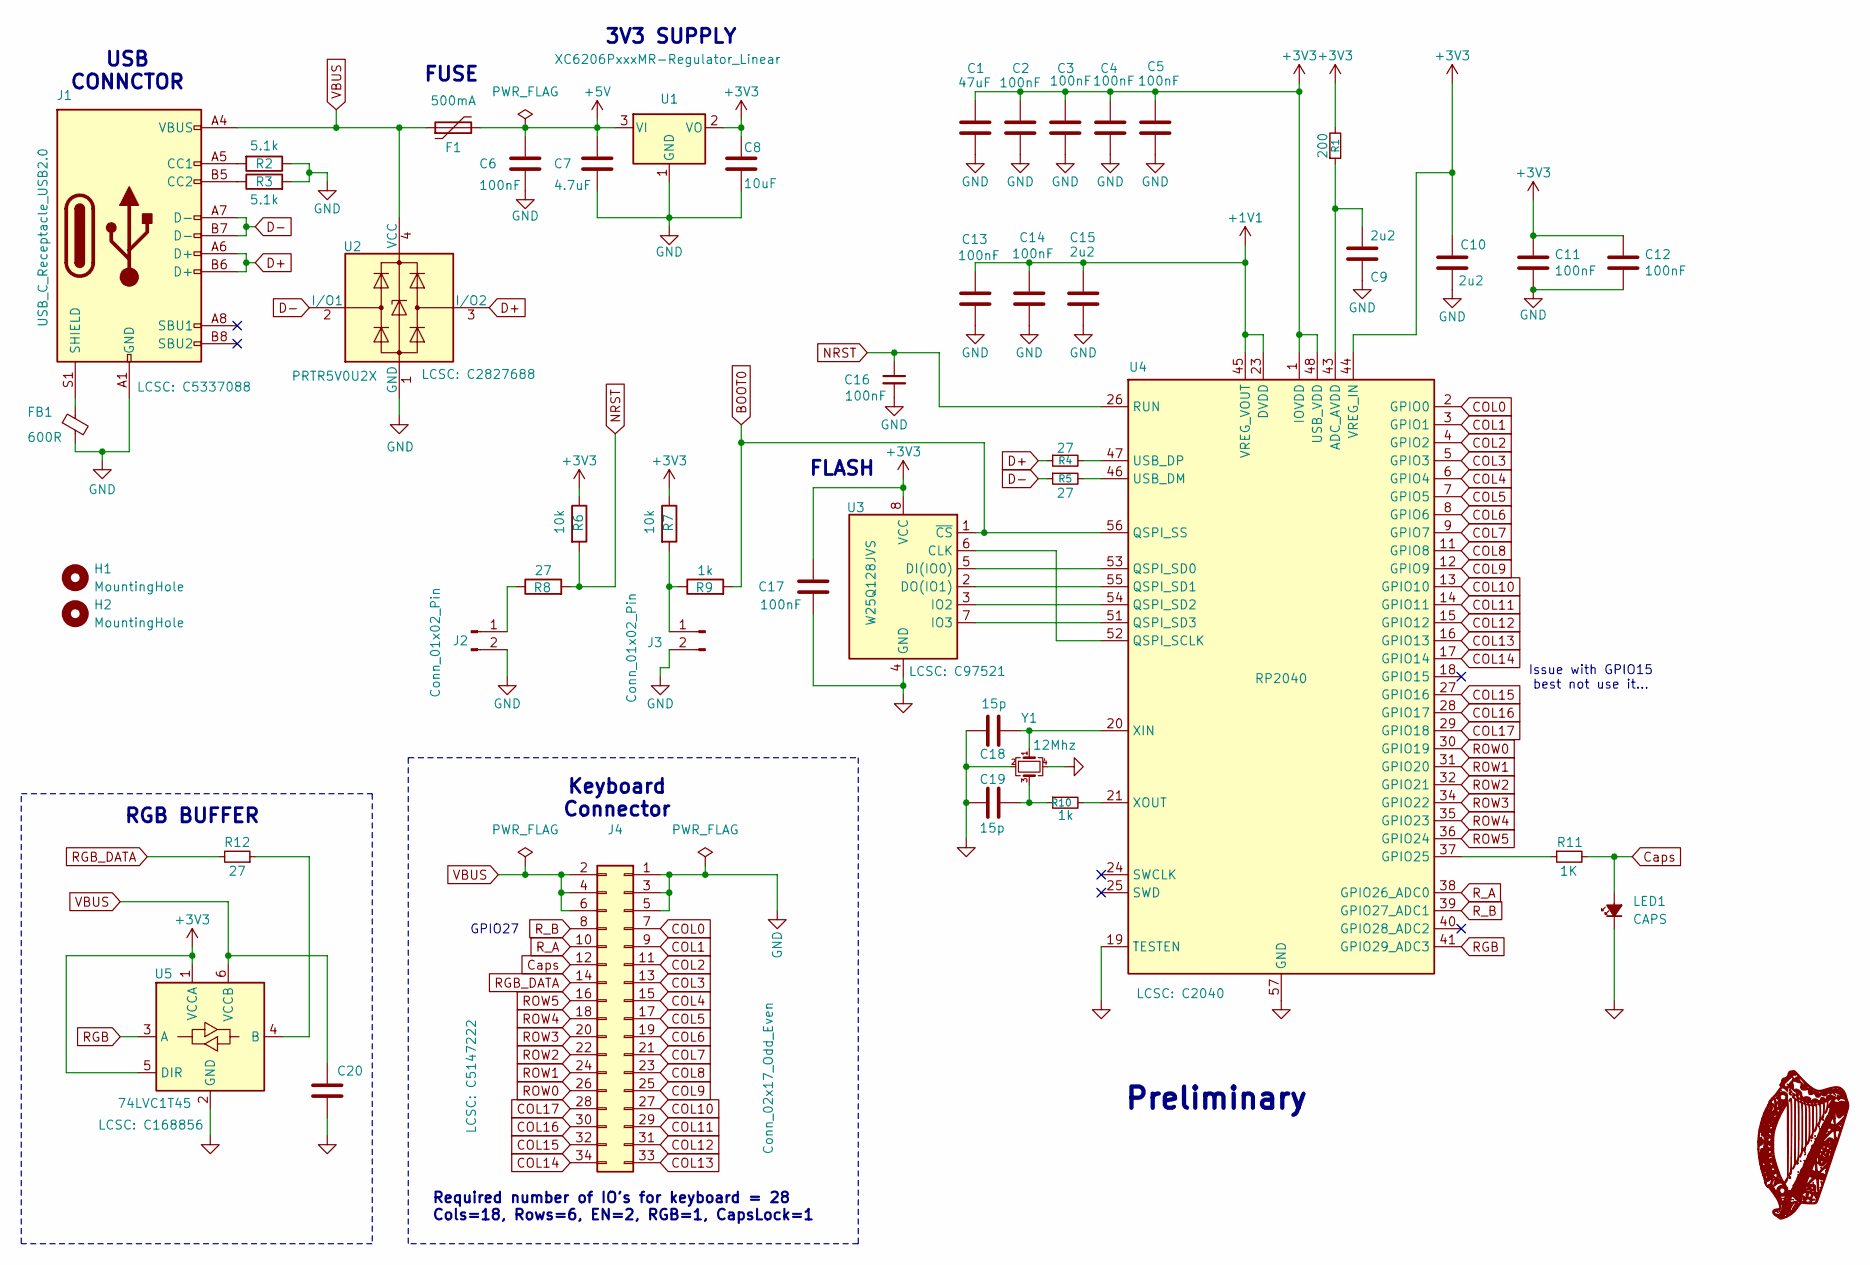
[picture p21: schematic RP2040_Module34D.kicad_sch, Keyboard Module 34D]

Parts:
C1: 47uF; C_0805_2012Metric; MPN# CL21A476MQYNNNE; LCSC C16780
C2, C3, C4, C11, C12, C13, C14, C20: 100nF; C_0402_1005Metric; MPN# CL05B104KB54PNC; LCSC C307331
C5, C16, C17: 100nF; C_0402_1005Metric; LCSC C307331
C6: 100nF; C_0402_1005Metric; MPN CL05B104KB54PNC; LCSC C307331
C7: 4.7uF; C_0805_2012Metric; MPN# CL21A475KAQNNNE; LCSC C1779
C8: 10uF; C_0805_2012Metric; LCSC C307331
C9, C10, C15: 2u2; C_0805_2012Metric; MPN# CL21B225KAFNNNE; LCSC C19110
C18: 15p; C_0402_1005Metric; MPN# CL05C150JB5NNNC; LCSC C86285
C19: 15p; C_0402_1005Metric; MPN# CL05C150JB5NNNC; LCSC C307331 OR C86285
F1: 500mA; Fuse_1206_3216Metric; MPN# ASMD1206-150; LCSC C135341
FB1: 600R; BEADC1608X95N; MPN# BLM18AG601SN1D; LCSC C19330
H1, H2: MountingHole; MountingHole_2.2mm_M2
J1: USB_C_Receptacle_USB2.0; USB_C_31-M-12; JlcRotOffset 180
J2, J3: Conn_01x02_Pin; PinHeader_1x02_P2.54mm_Vertical
J4: Conn_02x17_Odd_Even; IDC_2X17_1.27MM; MPN# X1270WV-2x17B-6TV01; LCSC C5147222
LED1: CAPS; LED_0805_2012Metric; MPN# D-B080508B1-KS2; LCSC C108412
R1: 200; R_0402_1005Metric; LCSC# C25087
R2: 5.1k; R_0402_1005Metric; MPN# 0402WGF5101TCE
R3: 5.1k; R_0402_1005Metric; MPN# 0402WGF5101TCE; LCSC C25905
R4, R5: 27; R_0402_1005Metric
R6: 10k; R_0402_1005Metric; MPN# 0402WGF1002TCE; LCSC C25744
R7: 10k; R_0402_1005Metric
R8: 27; R_0402_1005Metric; MPN# 0402WGF270JTCE
R9, R10: 1k; R_0402_1005Metric; MPN# 0402WGF1001TCE; LCSC C11702
R11: 1K; R_0402_1005Metric; MPN# 0402WGF1001TCE; LCSC C11702
R12: 27; R_0402_1005Metric; LCSC C25100
U1: XC6206PxxxMR-Regulator_Linear; SOT-23; LCSC C5446
U2: PRTR5V0U2X; SOT-143; LCSC C2827688
U3: W25Q128JVS; SOIC_128JVSIQ_WIN; Mfr. Part # W25Q128JVSIQ; LCSC C97521
U4: RP2040; QFN-56-1EP_7x7mm_P0.4mm_EP3.2x3.2mm; LCSC C2040
U5: 74LVC1T45; SOT-26; MPN # 74LVC1T45W6-7; JLCPCB_CORRECTION 0; 0; 270
Y1: 12Mhz; Crystal_SMD_3225-4Pin_3.2x2.5mm; LCSC C20625731

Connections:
+1V1: C13.1, C14.1, C15.1, U4.23 (DVDD), U4.45 (VREG_VOUT), U4.50 (DVDD)
+3V3: C1.1, C2.1, C3.1, C4.1, C5.1, C8.1, C10.1, C11.1, C12.1, C17.1, R1.2, R6.1, R7.1, U1.2 (VO), U3.8 (VCC), U4.1 (IOVDD), U4.10 (IOVDD), U4.22 (IOVDD), U4.33 (IOVDD), U4.42 (IOVDD), U4.44 (VREG_IN), U4.48 (USB_VDD), U4.49 (IOVDD), U5.1 (VCCA), U5.5 (DIR)
+5V: C6.1, C7.1, F1.2, U1.3 (VI)
BOOT0: R9.2, U3.1 (~CS), U4.56 (QSPI_SS)
COL0: J4.7, U4.2 (GPIO0)
COL1: J4.9, U4.3 (GPIO1)
COL2: J4.11, U4.4 (GPIO2)
COL3: J4.13, U4.5 (GPIO3)
COL4: J4.15, U4.6 (GPIO4)
COL5: J4.17, U4.7 (GPIO5)
COL6: J4.19, U4.8 (GPIO6)
COL7: J4.21, U4.9 (GPIO7)
COL8: J4.23, U4.11 (GPIO8)
COL9: J4.25, U4.12 (GPIO9)
COL10: J4.27, U4.13 (GPIO10)
COL11: J4.29, U4.14 (GPIO11)
COL12: J4.31, U4.15 (GPIO12)
COL13: J4.33, U4.16 (GPIO13)
COL14: J4.34, U4.17 (GPIO14)
COL15: J4.32, U4.27 (GPIO16)
COL16: J4.30, U4.28 (GPIO17)
COL17: J4.28, U4.29 (GPIO18)
Caps: J4.12, LED1.2 (A), R11.2
D+: J1.A6 (D+), J1.B6 (D+), R4.1, U2.3 (I/O2)
D-: J1.A7 (D-), J1.B7 (D-), R5.1, U2.2 (I/O1)
GND: C1.2, C2.2, C3.2, C4.2, C5.2, C6.2, C7.2, C8.2, C9.2, C10.2, C11.2, C12.2, C13.2, C14.2, C15.2, C16.2, C17.2, C18.2, C19.2, C20.2, FB1.2, J1.A1 (GND), J1.A12 (GND), J1.B1 (GND), J1.B12 (GND), J2.2, J3.2, J4.1, J4.3, J4.5, LED1.1 (K), R2.1, R3.2, U1.1 (GND), U2.1 (GND), U3.4 (GND), U4.19 (TESTEN), U4.57 (GND), U5.2 (GND), Y1.2, Y1.4
NRST: C16.1, R6.2, R8.2, U4.26 (RUN)
unnamed: C19.1, R10.1, Y1.3
unnamed: J1.A5 (CC1), R2.2
unnamed: J1.B5 (CC2), R3.1
unnamed: FB1.1, J1.S1 (SHIELD)
unnamed: J2.1, R8.1
unnamed: J3.1, R7.2, R9.1
unnamed: U3.6 (CLK), U4.52 (QSPI_SCLK)
unnamed: U3.5 (DI(IO0)), U4.53 (QSPI_SD0)
unnamed: U3.2 (DO(IO1)), U4.55 (QSPI_SD1)
unnamed: U3.3 (IO2), U4.54 (QSPI_SD2)
unnamed: U3.7 (IO3), U4.51 (QSPI_SD3)
unnamed: C9.1, R1.1, U4.43 (ADC_AVDD)
unnamed: R11.1, U4.37 (GPIO25)
unnamed: R5.2, U4.46 (USB_DM)
unnamed: R4.2, U4.47 (USB_DP)
unnamed: C18.1, U4.20 (XIN), Y1.1
unnamed: R10.2, U4.21 (XOUT)
unnamed: R12.1, U5.4 (B)
RGB: U4.41 (GPIO29_ADC3), U5.3 (A)
RGB_DATA: J4.14, R12.2
ROW0: J4.26, U4.30 (GPIO19)
ROW1: J4.24, U4.31 (GPIO20)
ROW2: J4.22, U4.32 (GPIO21)
ROW3: J4.20, U4.34 (GPIO22)
ROW4: J4.18, U4.35 (GPIO23)
ROW5: J4.16, U4.36 (GPIO24)
R_A: J4.10, U4.38 (GPIO26_ADC0)
R_B: J4.8, U4.39 (GPIO27_ADC1)
VBUS: C20.1, F1.1, J1.A4 (VBUS), J1.A9 (VBUS), J1.B4 (VBUS), J1.B9 (VBUS), J4.2, J4.4, J4.6, U2.4 (VCC), U5.6 (VCCB)

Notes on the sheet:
Preliminary
FLASH
FUSE
Keyboard Connector
Issue with GPIO15 best not use it...
3V3 SUPPLY
USB CONNCTOR
GPIO27
RGB BUFFER
Required number of IO's for keyboard = 28 Cols=18, Rows=6, EN=2, RGB=1, CapsLock=1

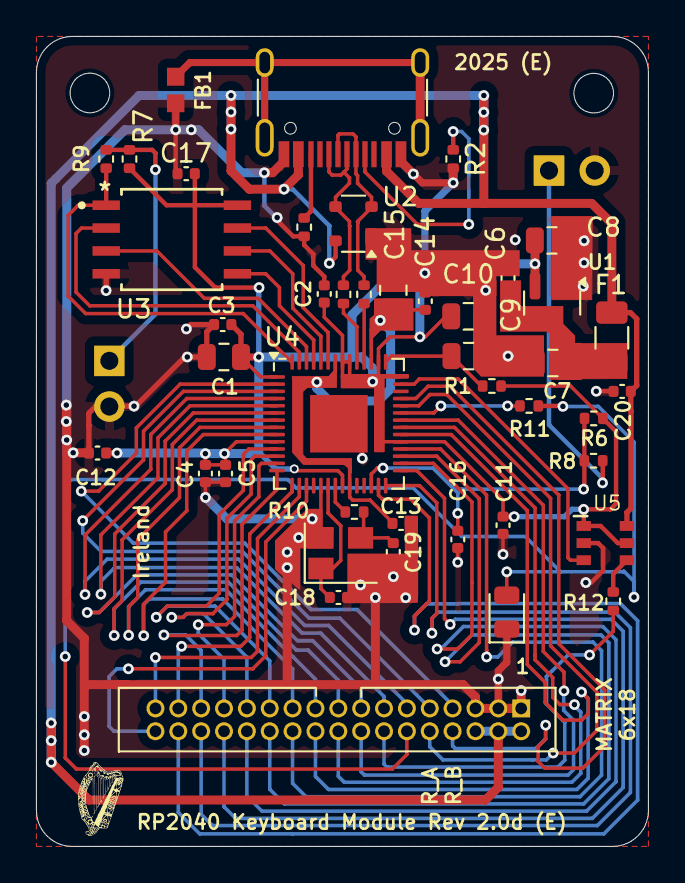
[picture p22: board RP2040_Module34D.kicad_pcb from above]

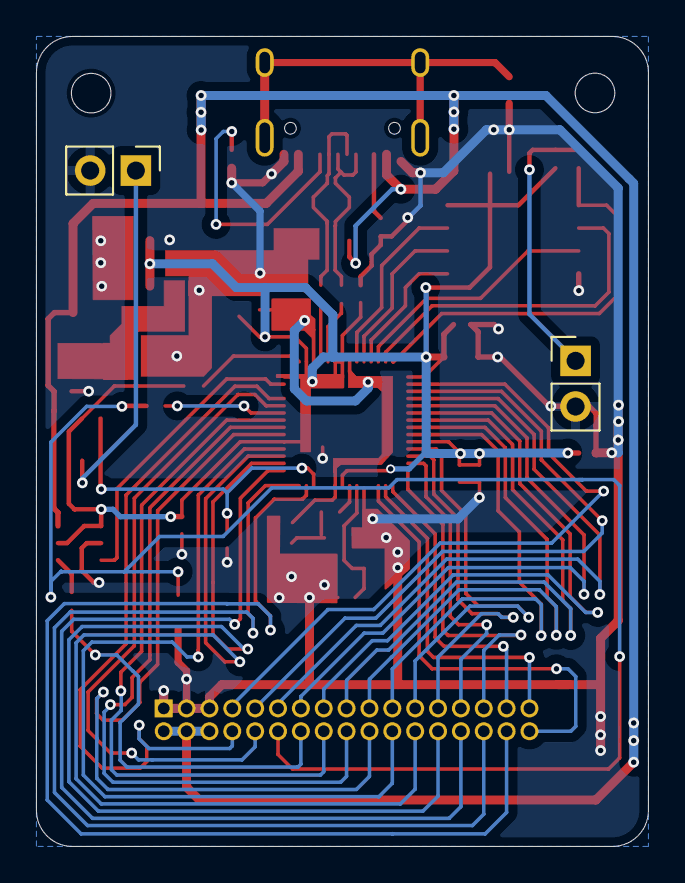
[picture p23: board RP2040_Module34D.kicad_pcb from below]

Board: 2 copper layers, 34.0 x 45.0 mm, 47 parts (2 on the bottom side), 56 nets.

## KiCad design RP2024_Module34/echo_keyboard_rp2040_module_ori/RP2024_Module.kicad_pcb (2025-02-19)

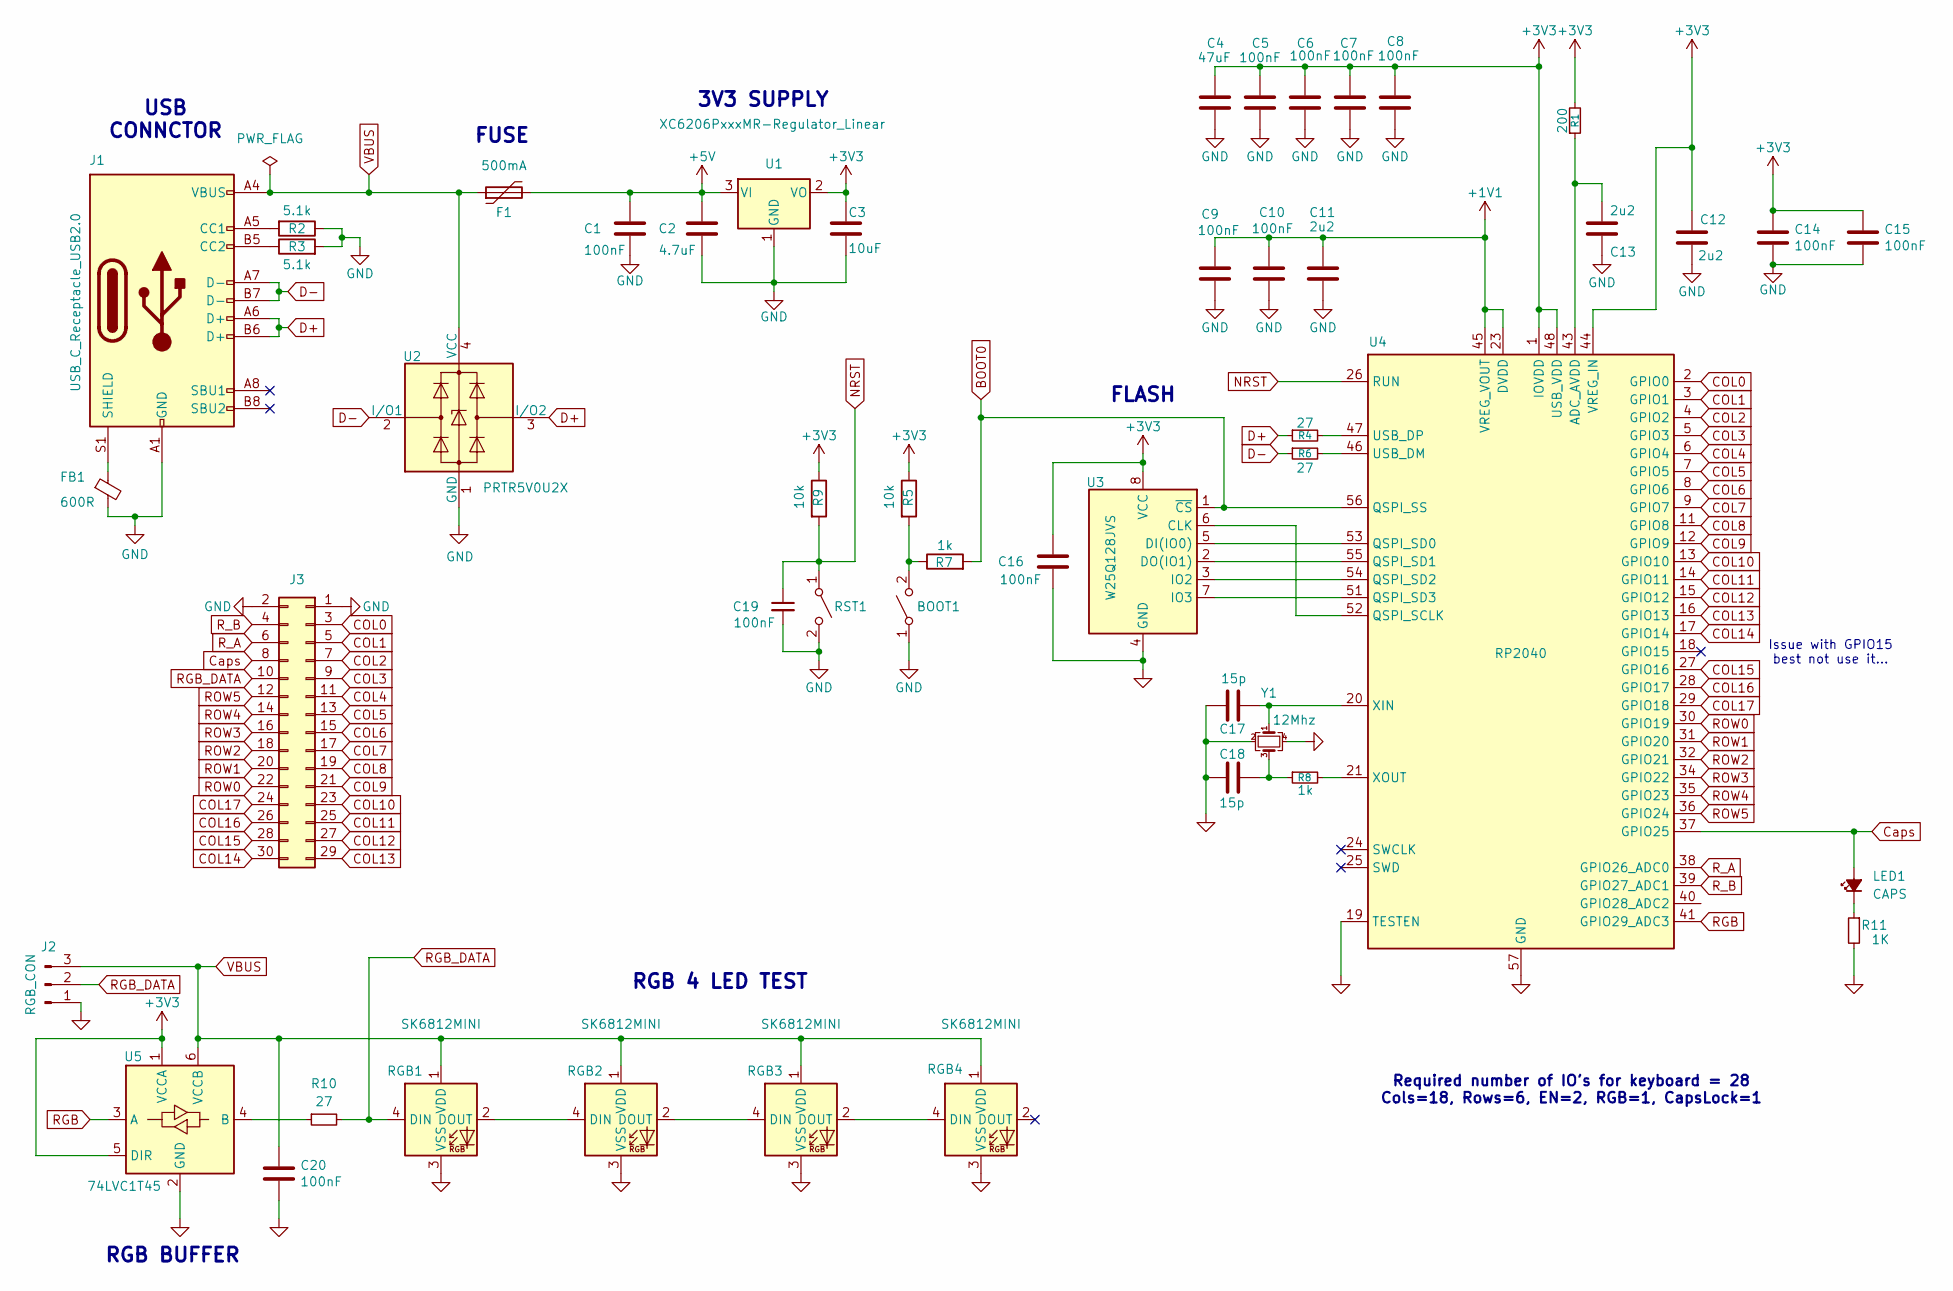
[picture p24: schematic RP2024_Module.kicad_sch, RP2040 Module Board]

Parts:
BOOT1: SW_SPST; SW_SPST_TL3342
C1, C5, C6, C7, C8, C9, C10, C14, C15, C16, C19, C20: 100nF; C_0402_1005Metric; LCSC C307331
C2: 4.7uF; C_0805_2012Metric; LCSC C307331
C3: 10uF; C_0805_2012Metric; LCSC C307331
C4: 47uF; C_0805_2012Metric; LCSC C307331
C11, C12, C13: 2u2; C_0805_2012Metric; LCSC C307331
C17, C18: 15p; C_0402_1005Metric; LCSC C307331
F1: 500mA; Fuse_1206_3216Metric; LCSC C135341
FB1: 600R; BEADC1608X95N
J1: USB_C_Receptacle_USB2.0; USB_C_31-M-12; JlcRotOffset 180
J2: RGB_CON; JST_EH_S3B-EH_1x03_P2.50mm_Horizontal; LCSC C263754
J3: Conn_02x15_Odd_Even; IDC_2X15_1.27MM; LCSC C5121680
LED1: CAPS; LED_0805_2012Metric
R1: 200; R_0402_1005Metric
R2, R3: 5.1k; R_0402_1005Metric
R4, R6: 27; R_0402_1005Metric
R5, R9: 10k; R_0402_1005Metric
R7, R8: 1k; R_0402_1005Metric
R10: 27; R_0402_1005Metric; LCSC C25100
R11: 1K; R_0402_1005Metric
RGB1: SK6812MINI; LED_SK6812MINI; LCSC C5149201
RGB2, RGB3, RGB4: SK6812MINI; LED_SK6812MINI
RST1: SW_SPST; SW_SPST_TL3342
U1: XC6206PxxxMR-Regulator_Linear; SOT-23; LCSC C5446
U2: PRTR5V0U2X; SOT-143; LCSC C2827688
U3: W25Q128JVS; SOIC_128JVSIQ_WIN; Mfr. Part # W25Q128JVSIQ; LCSC C97521
U4: RP2040; QFN-56-1EP_7x7mm_P0.4mm_EP3.2x3.2mm; LCSC C2040
U5: 74LVC1T45; SOT-26; MPN 74LVC1T45W6-7; JLCPCB_CORRECTION 0; 0; 270
Y1: 12Mhz; Crystal_SMD_3225-4Pin_3.2x2.5mm; LCSC C20625731

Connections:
+1V1: C9.1, C10.1, C11.1, U4.23 (DVDD), U4.45 (VREG_VOUT), U4.50 (DVDD)
+3V3: C3.1, C4.1, C5.1, C6.1, C7.1, C8.1, C12.1, C14.1, C15.1, C16.1, R1.2, R5.1, R9.1, U1.2 (VO), U3.8 (VCC), U4.1 (IOVDD), U4.10 (IOVDD), U4.22 (IOVDD), U4.33 (IOVDD), U4.42 (IOVDD), U4.44 (VREG_IN), U4.48 (USB_VDD), U4.49 (IOVDD), U5.1 (VCCA), U5.5 (DIR)
+5V: C1.1, C2.1, F1.2, U1.3 (VI)
BOOT0: R7.2, U3.1 (~CS), U4.56 (QSPI_SS)
COL0: J3.3, U4.2 (GPIO0)
COL1: J3.5, U4.3 (GPIO1)
COL2: J3.7, U4.4 (GPIO2)
COL3: J3.9, U4.5 (GPIO3)
COL4: J3.11, U4.6 (GPIO4)
COL5: J3.13, U4.7 (GPIO5)
COL6: J3.15, U4.8 (GPIO6)
COL7: J3.17, U4.9 (GPIO7)
COL8: J3.19, U4.11 (GPIO8)
COL9: J3.21, U4.12 (GPIO9)
COL10: J3.23, U4.13 (GPIO10)
COL11: J3.25, U4.14 (GPIO11)
COL12: J3.27, U4.15 (GPIO12)
COL13: J3.29, U4.16 (GPIO13)
COL14: J3.30, U4.17 (GPIO14)
COL15: J3.28, U4.27 (GPIO16)
COL16: J3.26, U4.28 (GPIO17)
COL17: J3.24, U4.29 (GPIO18)
Caps: J3.8, LED1.2 (A), U4.37 (GPIO25)
D+: J1.A6 (D+), J1.B6 (D+), R4.1, U2.3 (I/O2)
D-: J1.A7 (D-), J1.B7 (D-), R6.1, U2.2 (I/O1)
GND: BOOT1.1 (A), C1.2, C2.2, C3.2, C4.2, C5.2, C6.2, C7.2, C8.2, C9.2, C10.2, C11.2, C12.2, C13.2, C14.2, C15.2, C16.2, C17.2, C18.2, C19.2, C20.2, FB1.2, J1.A1 (GND), J1.A12 (GND), J1.B1 (GND), J1.B12 (GND), J2.1, J3.1, J3.2, R2.1, R3.2, R11.2, RGB1.3 (VSS), RGB2.3 (VSS), RGB3.3 (VSS), RGB4.3 (VSS), RST1.2 (B), U1.1 (GND), U2.1 (GND), U3.4 (GND), U4.19 (TESTEN), U4.57 (GND), U5.2 (GND), Y1.2, Y1.4
NRST: C19.1, R9.2, RST1.1 (A), U4.26 (RUN)
unnamed: BOOT1.2 (B), R5.2, R7.1
unnamed: C18.1, R8.1, Y1.3
unnamed: J1.A5 (CC1), R2.2
unnamed: J1.B5 (CC2), R3.1
unnamed: FB1.1, J1.S1 (SHIELD)
unnamed: LED1.1 (K), R11.1
unnamed: RGB1.2 (DOUT), RGB2.4 (DIN)
unnamed: RGB2.2 (DOUT), RGB3.4 (DIN)
unnamed: RGB3.2 (DOUT), RGB4.4 (DIN)
unnamed: U3.6 (CLK), U4.52 (QSPI_SCLK)
unnamed: U3.5 (DI(IO0)), U4.53 (QSPI_SD0)
unnamed: U3.2 (DO(IO1)), U4.55 (QSPI_SD1)
unnamed: U3.3 (IO2), U4.54 (QSPI_SD2)
unnamed: U3.7 (IO3), U4.51 (QSPI_SD3)
unnamed: C13.1, R1.1, U4.43 (ADC_AVDD)
unnamed: R6.2, U4.46 (USB_DM)
unnamed: R4.2, U4.47 (USB_DP)
unnamed: C17.1, U4.20 (XIN), Y1.1
unnamed: R8.2, U4.21 (XOUT)
unnamed: R10.1, U5.4 (B)
RGB: U4.41 (GPIO29_ADC3), U5.3 (A)
RGB_DATA: J2.2, J3.10, R10.2, RGB1.4 (DIN)
ROW0: J3.22, U4.30 (GPIO19)
ROW1: J3.20, U4.31 (GPIO20)
ROW2: J3.18, U4.32 (GPIO21)
ROW3: J3.16, U4.34 (GPIO22)
ROW4: J3.14, U4.35 (GPIO23)
ROW5: J3.12, U4.36 (GPIO24)
R_A: J3.6, U4.38 (GPIO26_ADC0)
R_B: J3.4, U4.39 (GPIO27_ADC1)
VBUS: C20.1, F1.1, J1.A4 (VBUS), J1.A9 (VBUS), J1.B4 (VBUS), J1.B9 (VBUS), J2.3, RGB1.1 (VDD), RGB2.1 (VDD), RGB3.1 (VDD), RGB4.1 (VDD), U2.4 (VCC), U5.6 (VCCB)

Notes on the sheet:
USB CONNCTOR
RGB BUFFER
FLASH
RGB 4 LED TEST
3V3 SUPPLY
FUSE
Issue with GPIO15 best not use it...
Required number of IO's for keyboard = 28 Cols=18, Rows=6, EN=2, RGB=1, CapsLock=1

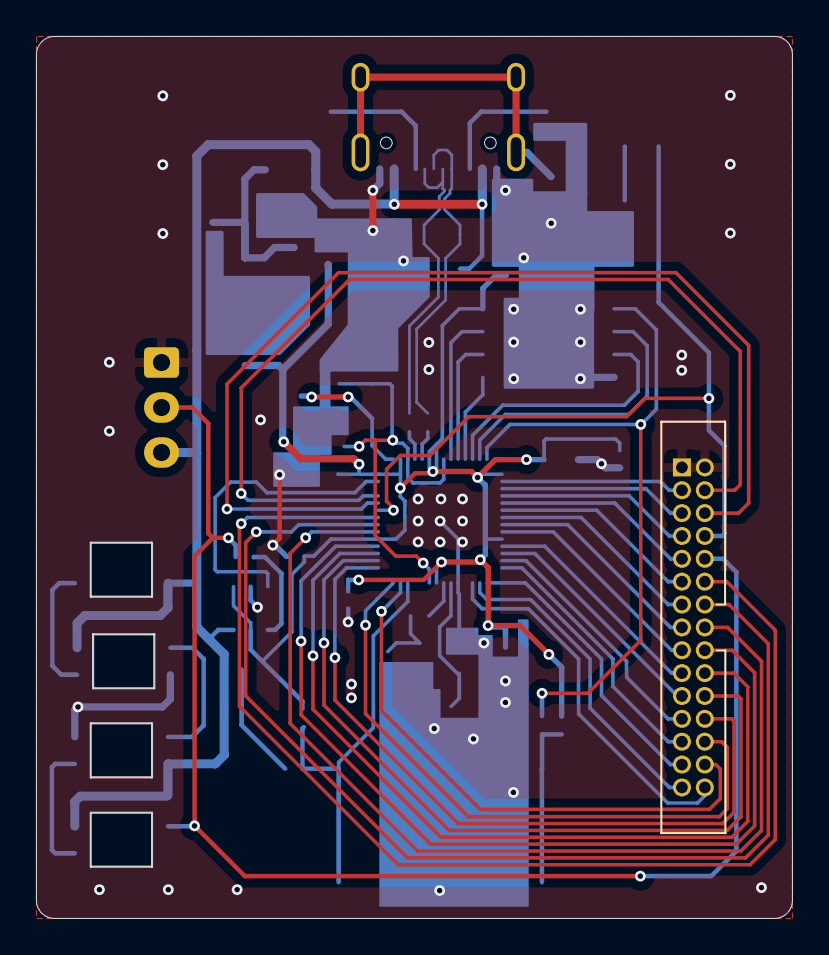
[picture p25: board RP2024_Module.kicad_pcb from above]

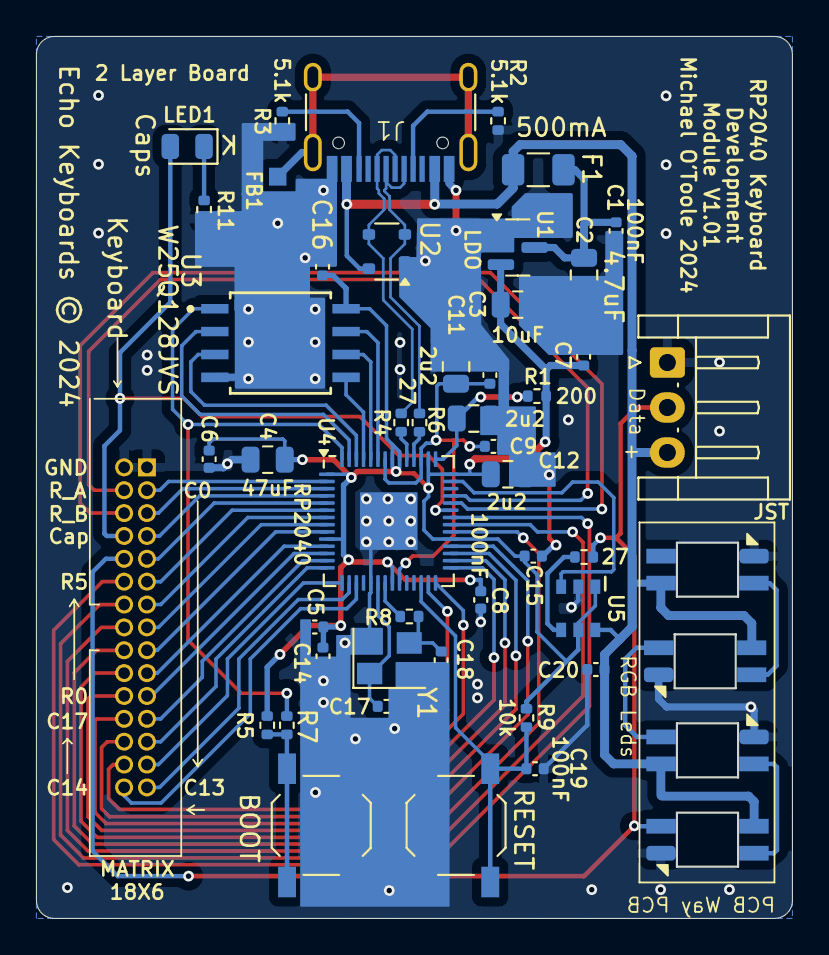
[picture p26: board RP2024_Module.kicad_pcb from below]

Board: 2 copper layers, 42.0 x 49.0 mm, 49 parts (44 on the bottom side), 58 nets.

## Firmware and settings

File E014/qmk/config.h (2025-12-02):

#pragma once

/* Double tap reset button to enter bootloader */
#define RP2040_BOOTLOADER_DOUBLE_TAP_RESET
#define RP2040_BOOTLOADER_DOUBLE_TAP_RESET_LED GP25
#define RP2040_BOOTLOADER_DOUBLE_TAP_RESET_TIMEOUT 500U

#define ENCODER_MAP_KEY_DELAY 10

#define WS2812_TIMING 1600
#define WS2812_T1H 700
#define WS2812_T0H 300
#define WS2812_TRST_US 300
#define WS2812_BYTE_ORDER WS2812_BYTE_ORDER_GRB

#define RGB_MATRIX_LED_COUNT 99

#define USB_MAX_POWER_CONSUMPTION 500
#define LED_CAPS_LOCK_PIN GP25
#define ENCODER_DIRECTION_FLIP

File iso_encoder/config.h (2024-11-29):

/* Copyright (C) 2024 Michael O'Toole
 *
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
 * You should have received a copy of the GNU General Public License
 * along with this program.  If not, see <http://www.gnu.org/licenses/>.
 */

#pragma once

#define USB_POLLING_INTERVAL_MS 1
#define WAIT_FOR_USB

#define MATRIX_ROWS 6
#define MATRIX_COLS 18

#define ENCODER_A_PINS { B8 }
#define ENCODER_B_PINS { B9 }
#define ENCODER_RESOLUTION 4
#define ENCODER_MAP_KEY_DELAY 10

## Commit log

2024-11-29 Update keymap.c
    update to current tested code
2024-11-29 Kicad Files
    [NewMXtest.kicad_pcb_bom.csv, NewMXtest.kicad_pcb_positions.csv, NewMXtest.kicad_sch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]
2024-11-29 Delete Echo_Ayla_Final/pcbway_production/2024-11-14-18-09-35/NewMXtest.kicad_pcb_gerber.zip
    Old file, will replace
2024-11-29 Add files via upload
    Kicad Files
    [NewMXtest.kicad_pcb_bom.csv, NewMXtest.kicad_pcb_positions.csv, NewMXtest.kicad_sch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]
2024-11-29 Delete iso_encoder/Echo_Ayla_Final/pcbway_production/2024-11-14-18-09-35/NewMXtest.kicad_pcb_gerber.zip
    Removed as it requires updating
2024-12-26 Update config.h
    Reduced RGB led count as SCRLK (OR PAUSE) not populated (replaced with encoder on right)
    [config.h]
2025-02-14 Update config.h
    Add flip encoder
    [config.h]
2025-02-14 Add files via upload
    Keyboard Development Module Rev 2.0
    [RP2024_Module.kicad_pcb, RP2024_Module.kicad_sch, RP2024_Module34.kicad_pcb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]
2025-02-14 Add files via upload
    Code for Module Board
2025-02-14 Create readme.md
    Note on connector and current for RGB
2025-02-19 Update config.h
    Added 1 rgb led to count
2025-02-19 Add files via upload
    Basic Keyboard Kicad Files
    [MXSwitches.kicad_sch, RP2040_Fullsize.kicad_sch, rgb.kicad_sch]
2025-02-19 Add files via upload
    Move file here
    [RP2024_Module34.kicad_pcb, RP2024_Module34.kicad_sch]
2025-02-19 Delete RP2024_Module34/RP2024_Module34.kicad_pcb
    moved
    [RP2024_Module34.kicad_pcb]
2025-02-19 Delete RP2024_Module34/RP2024_Module34.kicad_prl
    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
2025-02-19 Delete RP2024_Module34/RP2024_Module34.kicad_pro
    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
2025-02-19 Delete RP2024_Module34/RP2024_Module34.kicad_sch
    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
    [RP2024_Module34.kicad_sch]
2025-02-19 Add files via upload
    Original with test RGB leds
2025-02-19 Add files via upload
    This is the module fully tested and working, the original
    [RP2024_Module.kicad_pcb, RP2024_Module.kicad_sch]
2025-03-21 Files to create the extender board
    [adapter64.kicad_pcb, adapter64.kicad_sch]
2025-03-21 Add files via upload
    Added Gerber Files
2025-03-22 AKKO M1 Like Layout 60%
    [MXSwitches.kicad_sch, RP2040_Akko_M1_Like.kicad_pcb, RP2040_Akko_M1_Like.kicad_sch]
2025-03-22 Add files via upload
    Plate Graphic Files
    [2.5.dxf, 2.5sqr.dxf]
2025-06-18 Add files via upload
    Latest and last EN014 Basic Keyboard with 32 pin connector, uses rev 2.0 module
    [RP2040_Fullsize.kicad_sch, RP2040_Fullsize_Plate.kicad_pcb]
2025-06-18 Add files via upload
    DFX file for Plate
    [5mm3b_switch.dxf]
2025-06-27 Update readme.md
    Added notes on 3d printed case
2025-07-03 Add files via upload
    Module 34C
    [RP2024_Module34.kicad_pcb, RP2024_Module34.kicad_pcb_bom.csv, RP2024_Module34.kicad_pcb_bom_pcbway.csv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]
2025-07-21 Update readme.md
    Moved 3d case info to main page
2025-07-22 Add files via upload
    Printed Plate
2025-12-02 Update config.h
    Flip encoder, add caps lock pin
    [config.h]
2025-12-17 Rev D files
    [RP2040_Module34D.kicad_pcb]
2026-01-14 Delete 34 Pin Extender Board/adapter64.kicad_pcb_gerber.zip
    Wrong Silkscreen (mirored)
2026-01-14 Add files via upload
    Updated gerbers
2026-01-14 Add files via upload
    Updates
    [adapter64.kicad_pcb]

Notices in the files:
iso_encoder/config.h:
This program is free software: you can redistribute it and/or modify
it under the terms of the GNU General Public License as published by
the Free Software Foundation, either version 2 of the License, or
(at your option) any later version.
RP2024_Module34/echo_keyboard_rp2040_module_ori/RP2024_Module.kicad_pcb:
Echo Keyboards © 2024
